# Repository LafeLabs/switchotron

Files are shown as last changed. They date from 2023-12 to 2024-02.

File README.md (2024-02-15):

# [SWITCHOTRON](https://github.com/lafelabs/switchotron/)

### [localhost](http://localhost/)

## 6 channel switch control code:

```

#include <Adafruit_NeoPixel.h>
#ifdef __AVR__
#endif

// Which pin on the Arduino is connected to the NeoPixels?
#define PIN        12 // On Trinket or Gemma, suggest changing this to 1

// How many NeoPixels are attached to the Arduino?
#define NUMPIXELS 6 // Popular NeoPixel ring size
//there are 8 neopixels but this code is for 6 used along with 6 buttons

// When setting up the NeoPixel library, we tell it how many pixels,  
// and which pin to use to send signals. Note that for older NeoPixel
// strips you might need to change the third parameter -- see the
// strandtest example for more information on possible values.
Adafruit_NeoPixel pixels(NUMPIXELS, PIN, NEO_GRB + NEO_KHZ800);

int analog = 0;
int delta = 100;
int mode = 1;//modes are 1,2,3,4,5, and 6 which are pixel 5,4,3,2,1, and 0 respectively

void setup() {
   Serial.begin(115200);

  // These lines are specifically to support the Adafruit Trinket 5V 16 MHz.
  // Any other board, you can remove this part (but no harm leaving it):
#if defined(__AVR_ATtiny85__) && (F_CPU == 16000000)
  clock_prescale_set(clock_div_1);
#endif
  // END of Trinket-specific code.

    pinMode(3,OUTPUT);
    pinMode(4,OUTPUT);
    pinMode(5,OUTPUT);
    pinMode(6,OUTPUT);
    pinMode(7,OUTPUT);
    pinMode(8,OUTPUT);

    digitalWrite(3,LOW);
    digitalWrite(4,LOW);
    digitalWrite(5,LOW);
    digitalWrite(6,LOW);
    digitalWrite(7,LOW);
    digitalWrite(8,LOW);

  pixels.begin(); // INITIALIZE NeoPixel strip object (REQUIRED)

}

void loop() {
  pixels.clear(); // Set all pixel colors to 'off'
  analog = analogRead(A0);
  // The first NeoPixel in a strand is #0, second is 1, all the way up
  // to the count of pixels minus one.
  
  if(analog > 1024 - delta){
    delay(1);
    analog = analogRead(A0);
    if(analog > 1023 - delta){
       mode = 1;      
    }
  }
  if(analog > 781 - delta && analog < 781 + delta){
    delay(5);
    analog = analogRead(A0);
    if(analog > 781 - delta && analog < 781 + delta){
         mode = 2; 
    }
  }
  if(analog > 593 - delta && analog < 593 + delta){
     delay(5);
     analog = analogRead(A0);

    if(analog > 593 - delta && analog < 593 + delta){
      mode = 3;    
    }
  }

  if(analog > 436 - delta && analog < 436 + delta){
     delay(1);
     analog = analogRead(A0);

    if(analog > 436 - delta && analog < 436 + delta){
      mode = 4;    
    }
  }

  if(analog > 296 - delta && analog < 296 + delta){
     delay(1);
     analog = analogRead(A0);

    if(analog > 296 - delta && analog < 296 + delta){
      mode = 5;    
    }
  }

  if(analog > 154 - delta && analog < 154 + delta){
     delay(1);
     analog = analogRead(A0);

    if(analog > 154 - delta && analog < 154 + delta){
      mode = 6;    
    }
  }

  if (Serial.available()) {

    //for more info on this code see http://adam-meyer.com/arduino/arduino-serial
    //read serial as ascii integer
        int ser = Serial.read();
    //    Serial.println(ser);
     if(ser == 49){    //ASCII for 1
      mode = 1;
     }
     if(ser == 50){    //ASCII for 2
      mode = 2;
     }
     if(ser == 51){    //ASCII for 3
      mode = 3;
     }
     if(ser == 52){    //ASCII for 4
      mode = 4;
     }
     if(ser == 53){    //ASCII for 5
      mode = 5;
     }
     if(ser == 54){    //ASCII for 6
      mode = 6;
     }

  }

  if(mode == 1){
    pixels.setPixelColor(0, pixels.Color(0, 0, 0));    
    pixels.setPixelColor(1, pixels.Color(0, 0, 0));    
    pixels.setPixelColor(2, pixels.Color(0, 0, 0));    
    pixels.setPixelColor(3, pixels.Color(0, 0, 0));    
    pixels.setPixelColor(4, pixels.Color(0, 0, 0));    
    pixels.setPixelColor(5, pixels.Color(255, 0, 0));    

    digitalWrite(3,HIGH);
    digitalWrite(4,LOW);
    digitalWrite(5,LOW);
    digitalWrite(6,LOW);
    digitalWrite(7,LOW);
    digitalWrite(8,LOW);
    
  }
  if(mode == 2){
    pixels.setPixelColor(0, pixels.Color(0, 0, 0));    
    pixels.setPixelColor(1, pixels.Color(0, 0, 0));    
    pixels.setPixelColor(2, pixels.Color(0, 0, 0));    
    pixels.setPixelColor(3, pixels.Color(0, 0, 0));    
    pixels.setPixelColor(4, pixels.Color(255, 165, 0));    
    pixels.setPixelColor(5, pixels.Color(0, 0, 0));    
    digitalWrite(3,LOW);
    digitalWrite(4,HIGH);
    digitalWrite(5,LOW);
    digitalWrite(6,LOW);
    digitalWrite(7,LOW);
    digitalWrite(8,LOW);
 
  }
  if(mode == 3){
    pixels.setPixelColor(0, pixels.Color(0, 0, 0));    
    pixels.setPixelColor(1, pixels.Color(0, 0, 0));    
    pixels.setPixelColor(2, pixels.Color(0, 0, 0));    
    pixels.setPixelColor(3, pixels.Color(255, 215, 0));    
    pixels.setPixelColor(4, pixels.Color(0, 0, 0));    
    pixels.setPixelColor(5, pixels.Color(0, 0, 0));    
    digitalWrite(3,LOW);
    digitalWrite(4,LOW);
    digitalWrite(5,HIGH);
    digitalWrite(6,LOW);
    digitalWrite(7,LOW);
    digitalWrite(8,LOW);
  }
  if(mode == 4){
    pixels.setPixelColor(0, pixels.Color(0, 0, 0));    
    pixels.setPixelColor(1, pixels.Color(0, 0, 0));    
    pixels.setPixelColor(2, pixels.Color(0, 255, 0));    
    pixels.setPixelColor(3, pixels.Color(0, 0, 0));    
    pixels.setPixelColor(4, pixels.Color(0, 0, 0));    
    pixels.setPixelColor(5, pixels.Color(0, 0, 0));    
    digitalWrite(3,LOW);
    digitalWrite(4,LOW);
    digitalWrite(5,LOW);
    digitalWrite(6,HIGH);
    digitalWrite(7,LOW);
    digitalWrite(8,LOW);
  }
  if(mode == 5){
    pixels.setPixelColor(0, pixels.Color(0, 0, 0));    
    pixels.setPixelColor(1, pixels.Color(0, 0, 255));    
    pixels.setPixelColor(2, pixels.Color(0, 0, 0));    
    pixels.setPixelColor(3, pixels.Color(0, 0, 0));    
    pixels.setPixelColor(4, pixels.Color(0, 0, 0));    
    pixels.setPixelColor(5, pixels.Color(0, 0, 0));    
    digitalWrite(3,LOW);
    digitalWrite(4,LOW);
    digitalWrite(5,LOW);
    digitalWrite(6,LOW);
    digitalWrite(7,HIGH);
    digitalWrite(8,LOW);
  }
  if(mode == 6){
    pixels.setPixelColor(0, pixels.Color(200, 0, 200));    
    pixels.setPixelColor(1, pixels.Color(0, 0, 0));    
    pixels.setPixelColor(2, pixels.Color(0, 0, 0));    
    pixels.setPixelColor(3, pixels.Color(0, 0, 0));    
    pixels.setPixelColor(4, pixels.Color(0, 0, 0));    
    pixels.setPixelColor(5, pixels.Color(0, 0, 0));    
    digitalWrite(3,LOW);
    digitalWrite(4,LOW);
    digitalWrite(5,LOW);
    digitalWrite(6,LOW);
    digitalWrite(7,LOW);
    digitalWrite(8,HIGH);
  }
  
  pixels.show();   // Send the updated pixel colors to the hardware.
  delay(1); // Pause before next pass through loop

    Serial.println(analog);

}
```
## 9 Channel Control Code:

```

#include <Adafruit_NeoPixel.h>
#ifdef __AVR__
#endif

// Which pin on the Arduino is connected to the NeoPixels?
#define PIN        12 // On Trinket or Gemma, suggest changing this to 1

// How many NeoPixels are attached to the Arduino?
#define NUMPIXELS 9 // 
//there are 9

// When setting up the NeoPixel library, we tell it how many pixels,  
// and which pin to use to send signals. Note that for older NeoPixel
// strips you might need to change the third parameter -- see the
// strandtest example for more information on possible values.
Adafruit_NeoPixel pixels(NUMPIXELS, PIN, NEO_GRB + NEO_KHZ800);

int analog = 0;
int delta = 20;
int mode = 1;//modes are 1,2,3,4,5,6,7,8,9 which are pixel 8,7,6,5,4,3,2,1, and 0 respectively

void setup() {
    Serial.begin(115200);

  // These lines are specifically to support the Adafruit Trinket 5V 16 MHz.
  // Any other board, you can remove this part (but no harm leaving it):
#if defined(__AVR_ATtiny85__) && (F_CPU == 16000000)
  clock_prescale_set(clock_div_1);
#endif
  // END of Trinket-specific code.

    pinMode(3,OUTPUT);
    pinMode(4,OUTPUT);
    pinMode(5,OUTPUT);
    pinMode(6,OUTPUT);
    pinMode(7,OUTPUT);
    pinMode(8,OUTPUT);

    digitalWrite(3,LOW);
    digitalWrite(4,LOW);
    digitalWrite(5,LOW);
    digitalWrite(6,LOW);
    digitalWrite(7,LOW);
    digitalWrite(8,LOW);

  pixels.begin(); // INITIALIZE NeoPixel strip object (REQUIRED)

}

void loop() {

  pixels.clear(); // Set all pixel colors to 'off'
  analog = analogRead(A0);
  // The first NeoPixel in a strand is #0, second is 1, all the way up
  // to the count of pixels minus one.
  
  if(analog > 1024 - delta){
    delay(1);
    analog = analogRead(A0);
    if(analog > 1023 - delta){
       mode = 1;      
    }
  }
  if(analog > 836 - delta && analog < 836 + delta){
    delay(5);
    analog = analogRead(A0);
    if(analog > 836 - delta && analog < 836 + delta){
         mode = 2; 
    }
  }
  if(analog > 690 - delta && analog < 690 + delta){
     delay(5);
     analog = analogRead(A0);

    if(analog > 690 - delta && analog < 690 + delta){
      mode = 3;    
    }
  }

  if(analog > 569 - delta && analog < 569 + delta){
     delay(1);
     analog = analogRead(A0);

    if(analog > 569 - delta && analog < 569 + delta){
      mode = 4;    
    }
  }

  if(analog > 464 - delta && analog < 464 + delta){
     delay(1);
     analog = analogRead(A0);

    if(analog > 464 - delta && analog < 464 + delta){
      mode = 5;    
    }
  }

  if(analog > 372 - delta && analog < 372 + delta){
     delay(1);
     analog = analogRead(A0);

    if(analog > 372 - delta && analog < 372 + delta){
      mode = 6;    
    }
  }

  if(analog > 283 - delta && analog < 283 + delta){
     delay(1);
     analog = analogRead(A0);

    if(analog > 283 - delta && analog < 283 + delta){
      mode = 7;    
    }
  }

  if(analog > 195 - delta && analog < 195 + delta){
     delay(1);
     analog = analogRead(A0);

    if(analog > 195 - delta && analog < 195 + delta){
      mode = 8;    
    }
  }

  if(analog > 103 - delta && analog < 103 + delta){
     delay(1);
     analog = analogRead(A0);

    if(analog > 103 - delta && analog < 103 + delta){
      mode = 9;    
    }
  }

  if (Serial.available()) {

    //for more info on this code see http://adam-meyer.com/arduino/arduino-serial
    //read serial as ascii integer
     int ser = Serial.read();
    //    Serial.println(ser);
     if(ser == 49){    //ASCII for 1
      mode = 1;
     }
     if(ser == 50){    //ASCII for 2
      mode = 2;
     }
     if(ser == 51){    //ASCII for 3
      mode = 3;
     }
     if(ser == 52){    //ASCII for 4
      mode = 4;
     }
     if(ser == 53){    //ASCII for 5
      mode = 5;
     }
     if(ser == 54){    //ASCII for 6
      mode = 6;
     }
     if(ser == 55){    //ASCII for 4
      mode = 7;
     }
     if(ser == 56){    //ASCII for 5
      mode = 8;
     }
     if(ser == 57){    //ASCII for 6
      mode = 9;
     }

  }

  if(mode == 1){
    pixels.setPixelColor(0, pixels.Color(0, 0, 0));    
    pixels.setPixelColor(1, pixels.Color(0, 0, 0));    
    pixels.setPixelColor(2, pixels.Color(0, 0, 0));    
    pixels.setPixelColor(3, pixels.Color(0, 0, 0));    
    pixels.setPixelColor(4, pixels.Color(0, 0, 0));    
    pixels.setPixelColor(5, pixels.Color(0, 0, 0));    
    pixels.setPixelColor(6, pixels.Color(0, 0, 0));    
    pixels.setPixelColor(7, pixels.Color(0, 0, 0));    
    pixels.setPixelColor(8, pixels.Color(255, 0, 0));    
    digitalWrite(3,HIGH);
    digitalWrite(4,LOW);
    digitalWrite(5,LOW);
    digitalWrite(6,HIGH);
    digitalWrite(7,LOW);
    digitalWrite(8,LOW);

  }
  if(mode == 2){
    pixels.setPixelColor(0, pixels.Color(0, 0, 0));    
    pixels.setPixelColor(1, pixels.Color(0, 0, 0));    
    pixels.setPixelColor(2, pixels.Color(0, 0, 0));    
    pixels.setPixelColor(3, pixels.Color(0, 0, 0));    
    pixels.setPixelColor(4, pixels.Color(0, 0, 0));    
    pixels.setPixelColor(5, pixels.Color(0, 0, 0));    
    pixels.setPixelColor(6, pixels.Color(0, 0, 0));    
    pixels.setPixelColor(7, pixels.Color(255, 0, 0));    
    pixels.setPixelColor(8, pixels.Color(0, 0, 0));    
    digitalWrite(3,HIGH);
    digitalWrite(4,LOW);
    digitalWrite(5,LOW);
    digitalWrite(6,LOW);
    digitalWrite(7,HIGH);
    digitalWrite(8,LOW);

  }
  if(mode == 3){
    pixels.setPixelColor(0, pixels.Color(0, 0, 0));    
    pixels.setPixelColor(1, pixels.Color(0, 0, 0));    
    pixels.setPixelColor(2, pixels.Color(0, 0, 0));    
    pixels.setPixelColor(3, pixels.Color(0, 0, 0));    
    pixels.setPixelColor(4, pixels.Color(0, 0, 0));    
    pixels.setPixelColor(5, pixels.Color(0, 0, 0));    
    pixels.setPixelColor(6, pixels.Color(255, 0, 0));    
    pixels.setPixelColor(7, pixels.Color(0, 0, 0));    
    pixels.setPixelColor(8, pixels.Color(0, 0, 0));    
    digitalWrite(3,HIGH);
    digitalWrite(4,LOW);
    digitalWrite(5,LOW);
    digitalWrite(6,LOW);
    digitalWrite(7,LOW);
    digitalWrite(8,HIGH);

  }
  if(mode == 4){
    pixels.setPixelColor(0, pixels.Color(0, 0, 0));    
    pixels.setPixelColor(1, pixels.Color(0, 0, 0));    
    pixels.setPixelColor(2, pixels.Color(0, 0, 0));    
    pixels.setPixelColor(3, pixels.Color(0, 0, 0));    
    pixels.setPixelColor(4, pixels.Color(0, 0, 0));    
    pixels.setPixelColor(5, pixels.Color(255, 0, 0));    
    pixels.setPixelColor(6, pixels.Color(0, 0, 0));    
    pixels.setPixelColor(7, pixels.Color(0, 0, 0));    
    pixels.setPixelColor(8, pixels.Color(0, 0, 0));    
    digitalWrite(3,LOW);
    digitalWrite(4,HIGH);
    digitalWrite(5,LOW);
    digitalWrite(6,HIGH);
    digitalWrite(7,LOW);
    digitalWrite(8,LOW);

  }
  if(mode == 5){
    pixels.setPixelColor(0, pixels.Color(0, 0, 0));    
    pixels.setPixelColor(1, pixels.Color(0, 0, 0));    
    pixels.setPixelColor(2, pixels.Color(0, 0, 0));    
    pixels.setPixelColor(3, pixels.Color(0, 0, 0));    
    pixels.setPixelColor(4, pixels.Color(255, 0, 0));    
    pixels.setPixelColor(5, pixels.Color(0, 0, 0));    
    pixels.setPixelColor(6, pixels.Color(0, 0, 0));    
    pixels.setPixelColor(7, pixels.Color(0, 0, 0));    
    pixels.setPixelColor(8, pixels.Color(0, 0, 0));    
    digitalWrite(3,LOW);
    digitalWrite(4,HIGH);
    digitalWrite(5,LOW);
    digitalWrite(6,LOW);
    digitalWrite(7,HIGH);
    digitalWrite(8,LOW);

  }
  if(mode == 6){
    pixels.setPixelColor(0, pixels.Color(0, 0, 0));    
    pixels.setPixelColor(1, pixels.Color(0, 0, 0));    
    pixels.setPixelColor(2, pixels.Color(0, 0, 0));    
    pixels.setPixelColor(3, pixels.Color(255, 0, 0));    
    pixels.setPixelColor(4, pixels.Color(0, 0, 0));    
    pixels.setPixelColor(5, pixels.Color(0, 0, 0));    
    pixels.setPixelColor(6, pixels.Color(0, 0, 0));    
    pixels.setPixelColor(7, pixels.Color(0, 0, 0));    
    pixels.setPixelColor(8, pixels.Color(0, 0, 0));    
    digitalWrite(3,LOW);
    digitalWrite(4,HIGH);
    digitalWrite(5,LOW);
    digitalWrite(6,LOW);
    digitalWrite(7,LOW);
    digitalWrite(8,HIGH);

  }

  if(mode == 7){
    pixels.setPixelColor(0, pixels.Color(0, 0, 0));    
    pixels.setPixelColor(1, pixels.Color(0, 0, 0));    
    pixels.setPixelColor(2, pixels.Color(255, 0, 0));    
    pixels.setPixelColor(3, pixels.Color(0, 0, 0));    
    pixels.setPixelColor(4, pixels.Color(0, 0, 0));    
    pixels.setPixelColor(5, pixels.Color(0, 0, 0));    
    pixels.setPixelColor(6, pixels.Color(0, 0, 0));    
    pixels.setPixelColor(7, pixels.Color(0, 0, 0));    
    pixels.setPixelColor(8, pixels.Color(0, 0, 0));    
    digitalWrite(3,LOW);
    digitalWrite(4,LOW);
    digitalWrite(5,HIGH);
    digitalWrite(6,HIGH);
    digitalWrite(7,LOW);
    digitalWrite(8,LOW);

 }
  if(mode == 8){
    pixels.setPixelColor(0, pixels.Color(0, 0, 0));    
    pixels.setPixelColor(1, pixels.Color(255, 0, 0));    
    pixels.setPixelColor(2, pixels.Color(0, 0, 0));    
    pixels.setPixelColor(3, pixels.Color(0, 0, 0));    
    pixels.setPixelColor(4, pixels.Color(0, 0, 0));    
    pixels.setPixelColor(5, pixels.Color(0, 0, 0));    
    pixels.setPixelColor(6, pixels.Color(0, 0, 0));    
    pixels.setPixelColor(7, pixels.Color(0, 0, 0));    
    pixels.setPixelColor(8, pixels.Color(0, 0, 0));    
    digitalWrite(3,LOW);
    digitalWrite(4,LOW);
    digitalWrite(5,HIGH);
    digitalWrite(6,LOW);
    digitalWrite(7,HIGH);
    digitalWrite(8,LOW);

  }
  if(mode == 9){
    pixels.setPixelColor(0, pixels.Color(255, 0, 0));    
    pixels.setPixelColor(1, pixels.Color(0, 0, 0));    
    pixels.setPixelColor(2, pixels.Color(0, 0, 0));    
    pixels.setPixelColor(3, pixels.Color(0, 0, 0));    
    pixels.setPixelColor(4, pixels.Color(0, 0, 0));    
    pixels.setPixelColor(5, pixels.Color(0, 0, 0));    
    pixels.setPixelColor(6, pixels.Color(0, 0, 0));    
    pixels.setPixelColor(7, pixels.Color(0, 0, 0));    
    pixels.setPixelColor(8, pixels.Color(0, 0, 0));    
    digitalWrite(3,LOW);
    digitalWrite(4,LOW);
    digitalWrite(5,HIGH);
    digitalWrite(6,LOW);
    digitalWrite(7,LOW);
    digitalWrite(8,HIGH);

  }

  pixels.show();   // Send the updated pixel colors to the hardware.
  delay(1); // Pause before next pass through loop

//    Serial.println(analog);

}

```

The switch as sign, using GEOMETRON.

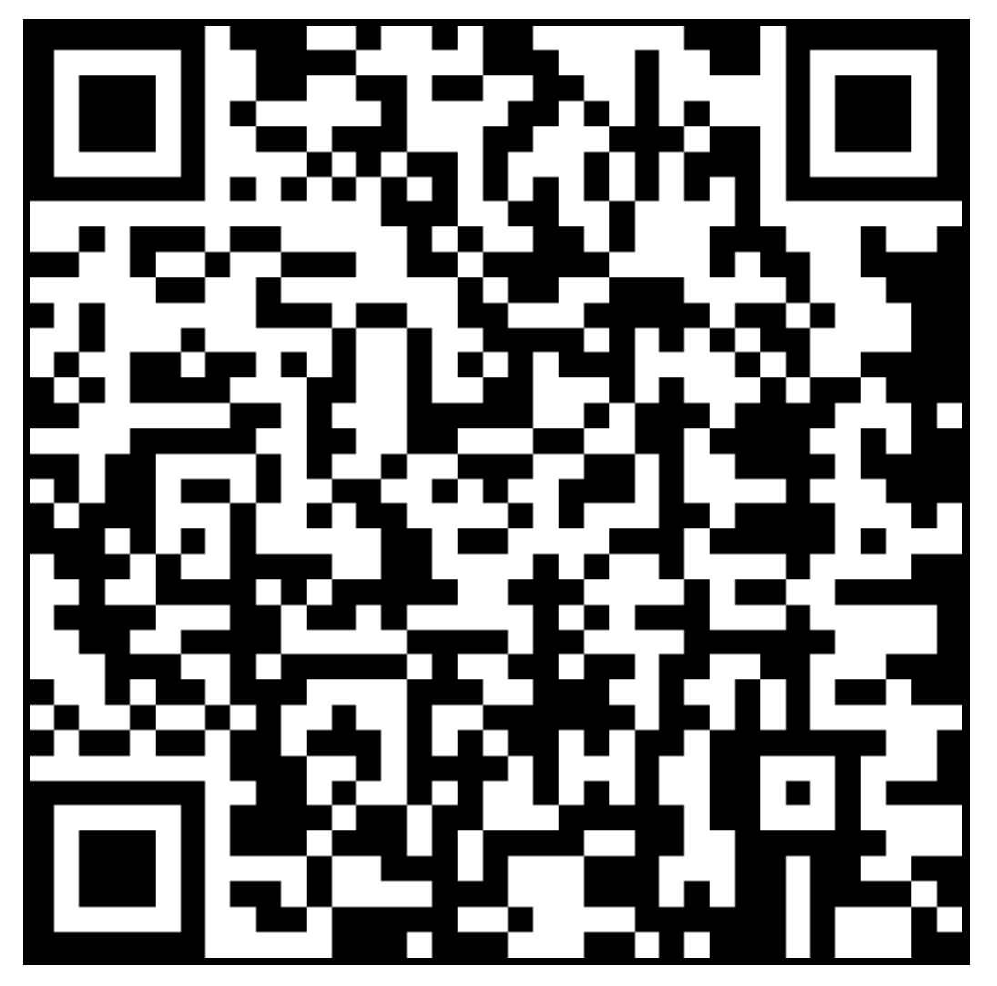
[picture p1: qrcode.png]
qr code pointing to github repository


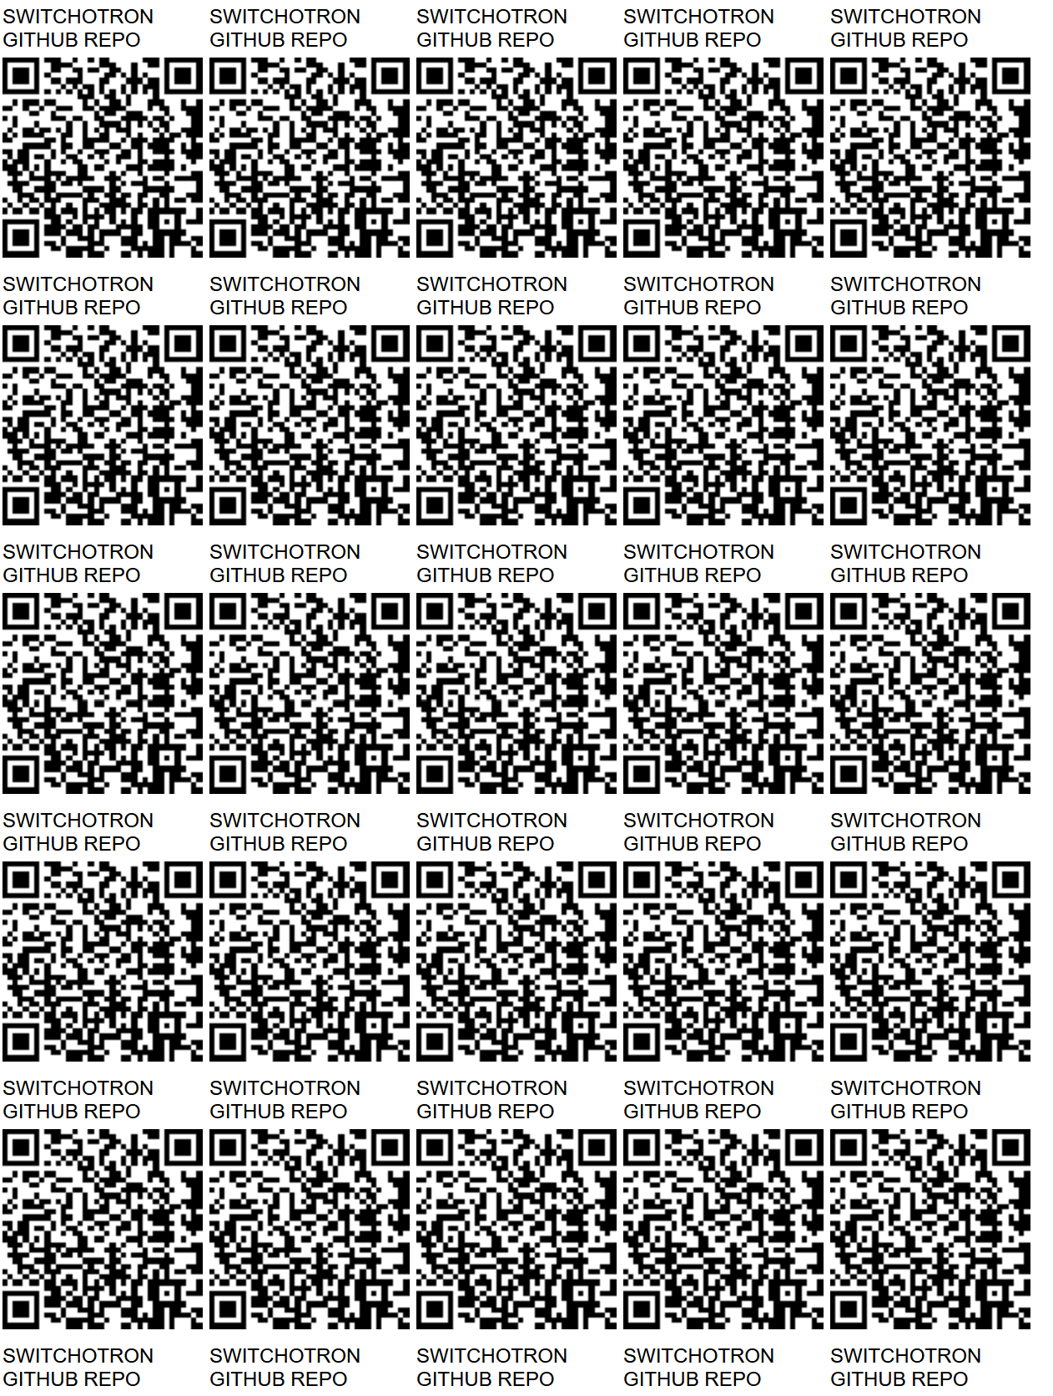
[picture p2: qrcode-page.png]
a whole page of qr codes to print out


This is a modular system of Arduino-based switch controllers for metrology.  The relay board is laid out on a 10 inch by 10 inch square, cut from acrylic or wood on a laser cutter or with a saw and drill.  

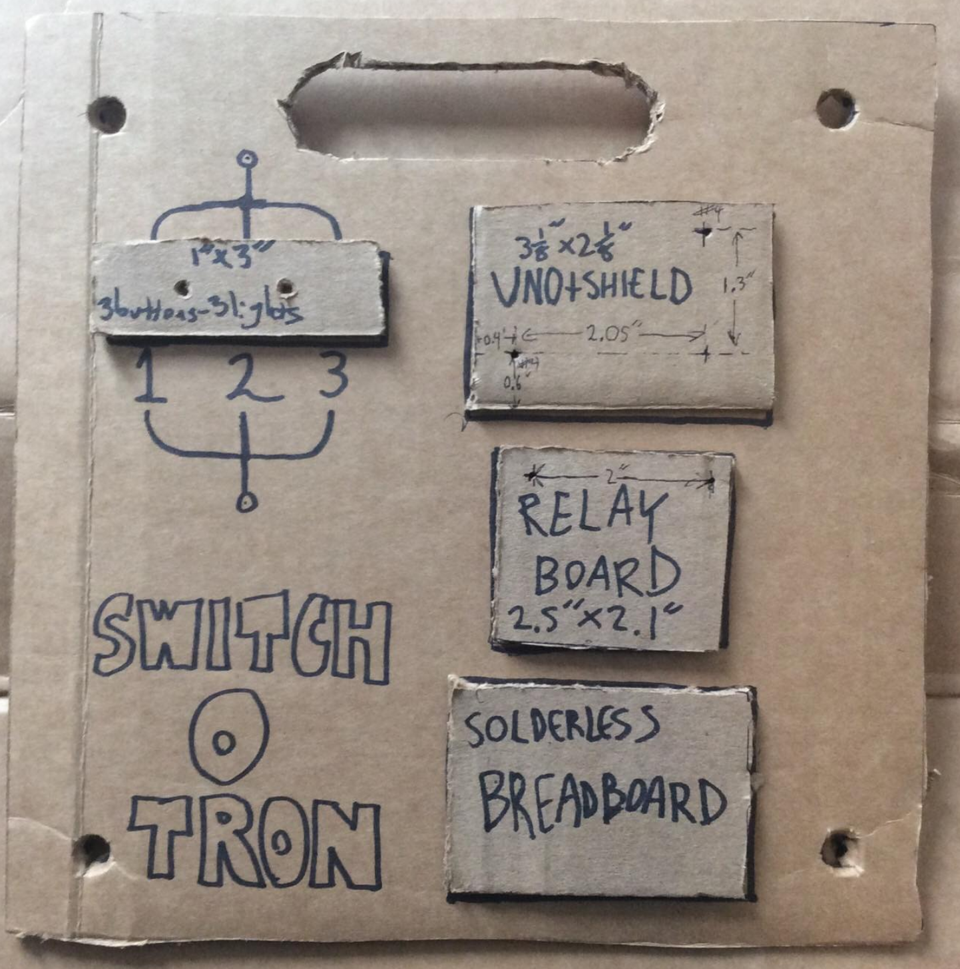
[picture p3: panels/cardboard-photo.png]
photo of cardboard model of system


pattern laid out in geometron of main square

# UNO SHIELD BOARD

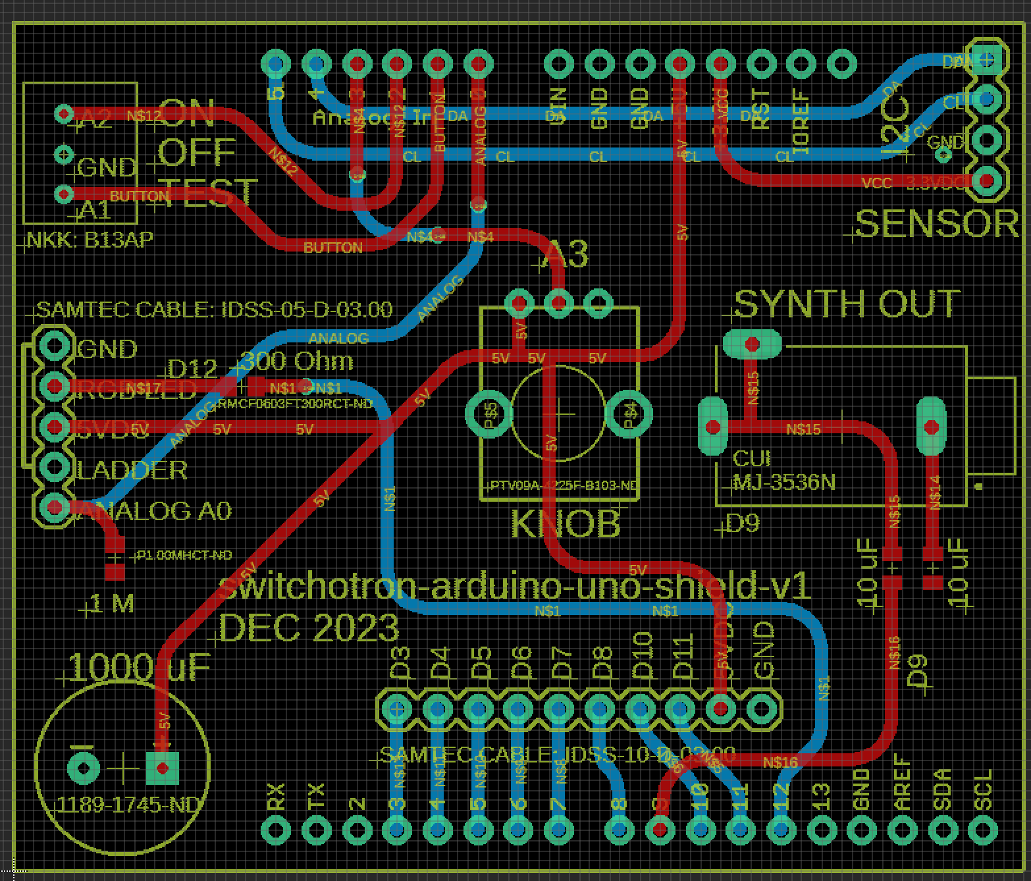
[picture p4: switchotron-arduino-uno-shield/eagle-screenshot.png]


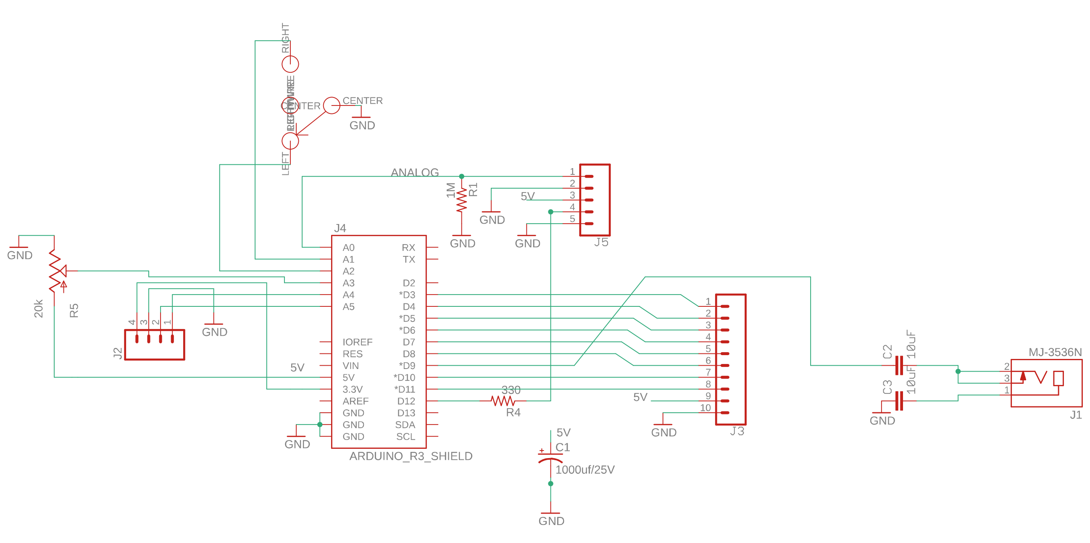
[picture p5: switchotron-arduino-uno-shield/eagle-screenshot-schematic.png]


### EAGLE FILES

 - [switchotron-arduino-uno-shield-v1.brd](https://raw.githubusercontent.com/LafeLabs/switchotron/main/switchotron-arduino-uno-shield/switchotron-arduino-uno-shield-v1.brd)
 - [switchotron-arduino-uno-shield-v1.sch](https://raw.githubusercontent.com/LafeLabs/switchotron/main/switchotron-arduino-uno-shield/switchotron-arduino-uno-shield-v1.sch)

### GERBER FILES

 - [switchotron-arduino-uno-shield-v1-gerbers.zip](https://github.com/LafeLabs/switchotron/raw/main/switchotron-arduino-uno-shield/switchotron-arduino-uno-shield-v1-gerbers.zip)

### PART LINKS

 - [Audio Jack part link on Digikey](https://www.digikey.com/en/products/detail/cui-devices/MJ-3536N/281264)
 - [10 uF SMT capacitor in 0603 package link on Digikey](https://www.digikey.com/en/products/detail/samsung-electro-mechanics/CL10A106MP8NNNC/3887529)
 - [1000 uF electrolytic capacitor link on Digikey](https://www.digikey.com/en/products/detail/rubycon/35PX1000MEFC10X20/3563769)
 - [300 Ohm SMT resistor in 0603 package link on Digikey](https://www.digikey.com/en/products/detail/stackpole-electronics-inc/RMCF0603FT300R/1760765)
 - [1 megaohm SMT resistor in 0603 package link on digikey](https://www.digikey.com/en/products/detail/panasonic-electronic-components/ERJ-3EKF1004V/196033)
 - [10 kiloohm potentiometer Digikey link](https://www.digikey.com/en/products/detail/bourns-inc/PTV09A-4225F-B103/3781155)
 - [Switch link on digikey](https://www.digikey.com/en/products/detail/nkk-switches/B13AP/379100)
 - [rainbow colored Male 0.1" header pin kit from Digikey/Adafruit](https://www.digikey.com/en/products/detail/adafruit-industries-llc/4154/10123805)
 - [SAMTEC IDSS-05-D-03.00 5 pin cable](https://www.samtec.com/products/idss-05-d-03.00)
 - [SAMTEC IDSS-10-D-03.00 10 pin cable](https://www.samtec.com/products/idss-10-d-03.00)
 - [SAMTEC datasheet](https://www.mouser.com/datasheet/2/527/idmd-2508302.pdf)

# 3 BUTTONS 3 LIGHTS BOARD

This board turned out to have the WS2811 pad on the first version, which is wrong!  The neopixel boards are all now the WS2812B.  

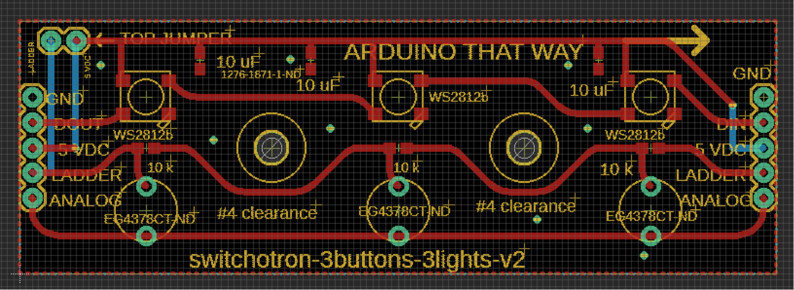
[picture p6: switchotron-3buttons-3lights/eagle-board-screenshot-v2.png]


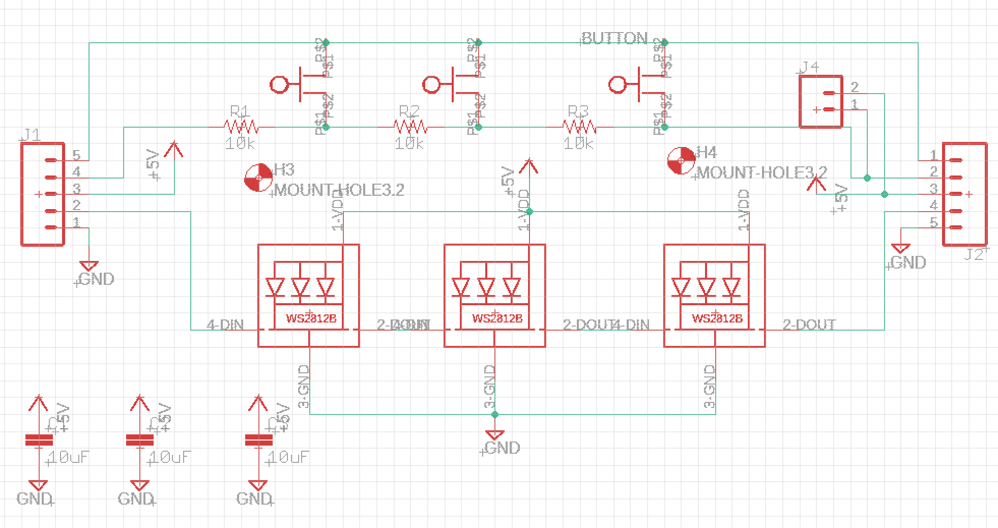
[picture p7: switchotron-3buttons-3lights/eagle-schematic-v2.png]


here is the version 1 board showing how the neopixel doesn't fit:

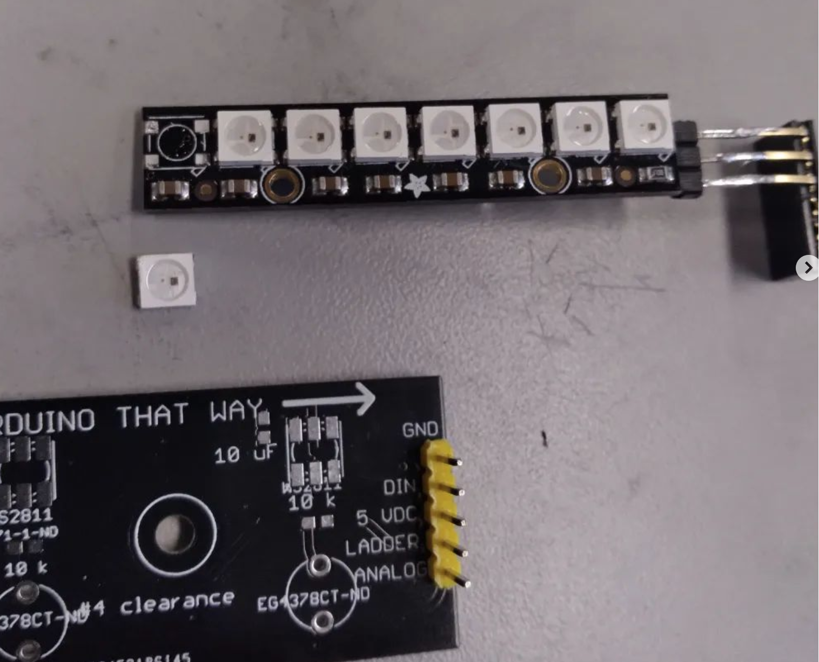
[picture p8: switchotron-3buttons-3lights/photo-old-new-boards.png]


WS2812 layout and pins:

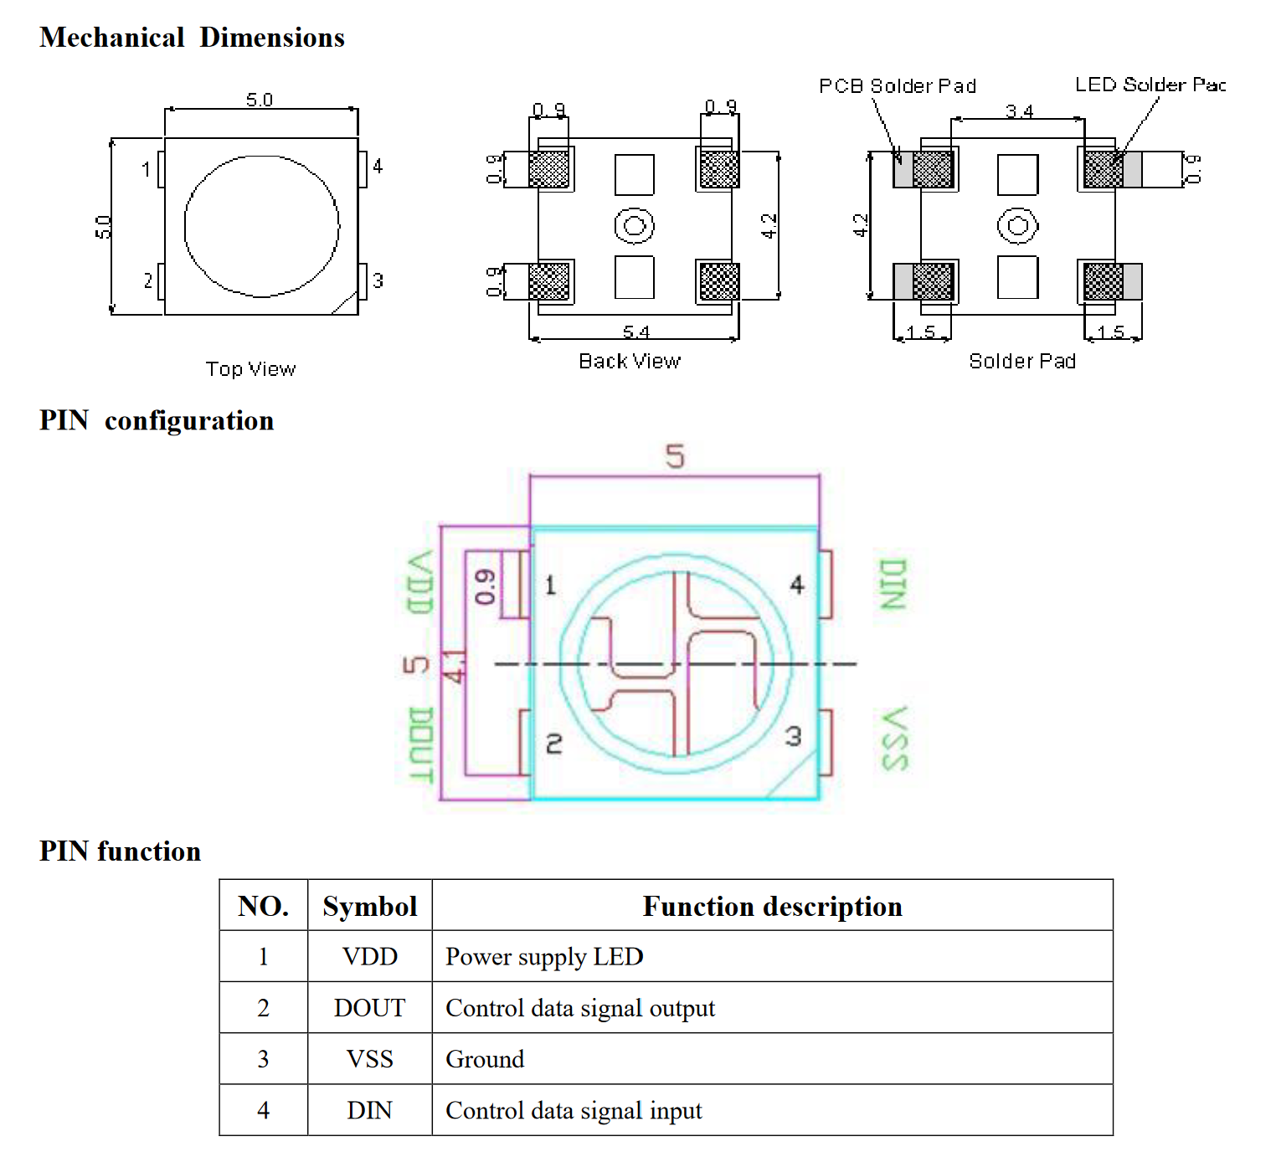
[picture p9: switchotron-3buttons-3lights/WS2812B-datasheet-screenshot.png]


#### EAGLE FILES

 - [switchotron-3buttons-3lights-v2.brd](https://raw.githubusercontent.com/LafeLabs/switchotron/main/switchotron-3buttons-3lights/switchotron-3buttons-3lights-v2.brd)
 - [switchotron-3buttons-3lights-v2.sch](https://raw.githubusercontent.com/LafeLabs/switchotron/main/switchotron-3buttons-3lights/switchotron-3buttons-3lights-v2.sch)

### GERBER FILES

 - [switchotron-3buttons-3lights-v2-gerbers.zip](https://github.com/LafeLabs/switchotron/raw/main/switchotron-3buttons-3lights/switchotron-3buttons-3lights-v2-gerbers.zip)

###  PARTS LINKS

 - [WS2812B LED NEOPIXELS](https://www.digikey.com/en/products/detail/sparkfun-electronics/COM-16347/11630204)
 - [10 uF Capacitors](https://www.digikey.com/en/products/detail/samsung-electro-mechanics/CL10A106MP8NNNC/3887529)
 - [10 k resistors](https://www.digikey.com/en/products/detail/stackpole-electronics-inc/RMCF0603FT10K0/1761235)
 - [buttons](https://www.digikey.com/en/products/detail/e-switch/TL59AF100Q/1144803)
 - [headers](https://www.digikey.com/en/products/detail/adafruit-industries-llc/4154/10123805)

# RELAY BOARD

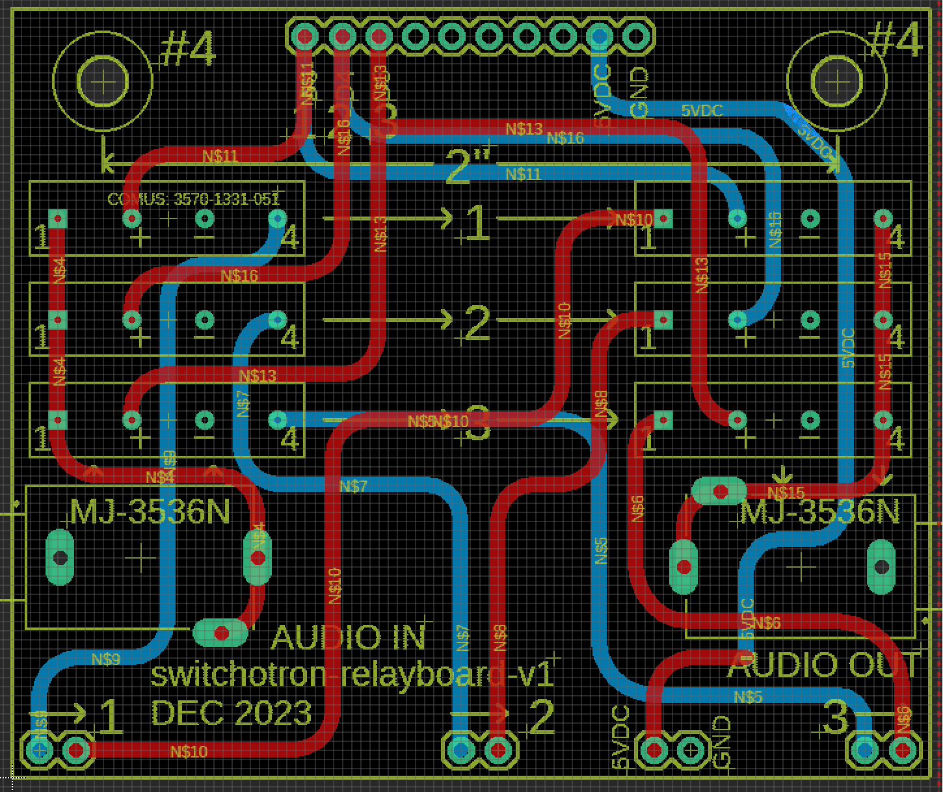
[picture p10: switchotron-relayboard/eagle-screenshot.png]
 

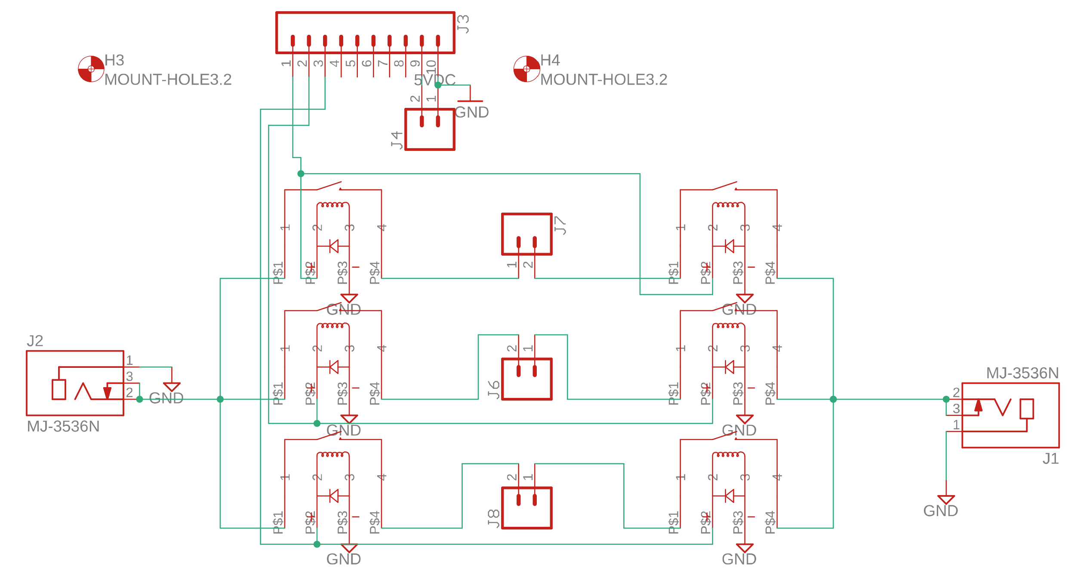
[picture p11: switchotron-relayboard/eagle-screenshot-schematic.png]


### EAGLE FILES

 - [switchotron-relayboard-v1.brd](https://raw.githubusercontent.com/LafeLabs/switchotron/main/switchotron-relayboard/switchotron-relayboard-v1.brd)
 - [switchotron-relayboard-v1.sch](https://raw.githubusercontent.com/LafeLabs/switchotron/main/switchotron-relayboard/switchotron-relayboard-v1.sch)

### GERBER FILES

 - [switchotron-relayboard-v1-gerbers.zip](https://github.com/LafeLabs/switchotron/raw/main/switchotron-3buttons-3lights/switchotron-relayboard-v1-gerbers.zip)

### PARTS LINKS

 - [Audio Jack part link on Digikey](https://www.digikey.com/en/products/detail/cui-devices/MJ-3536N/281264)
 - [headers](https://www.digikey.com/en/products/detail/adafruit-industries-llc/4154/10123805)
 - [relays](https://www.digikey.com/en/products/detail/comus-international/3570-1331-051/7497098)

#### LASER CUTOUTS AND DIMENSIONS

CUT ALL SQUARES OUT 10 INCHES ON A SIDE:









CUT THIS OUT 19X7 INCHES:



ADD OR MODIFY HOLE POSITIONS AS NEEDED FOR BOARD WHICH ADAPTS TO FRIDGE CABLE.  

### ARDUINO BOARD DIMENSIONS AND HOLE LAYOUTS

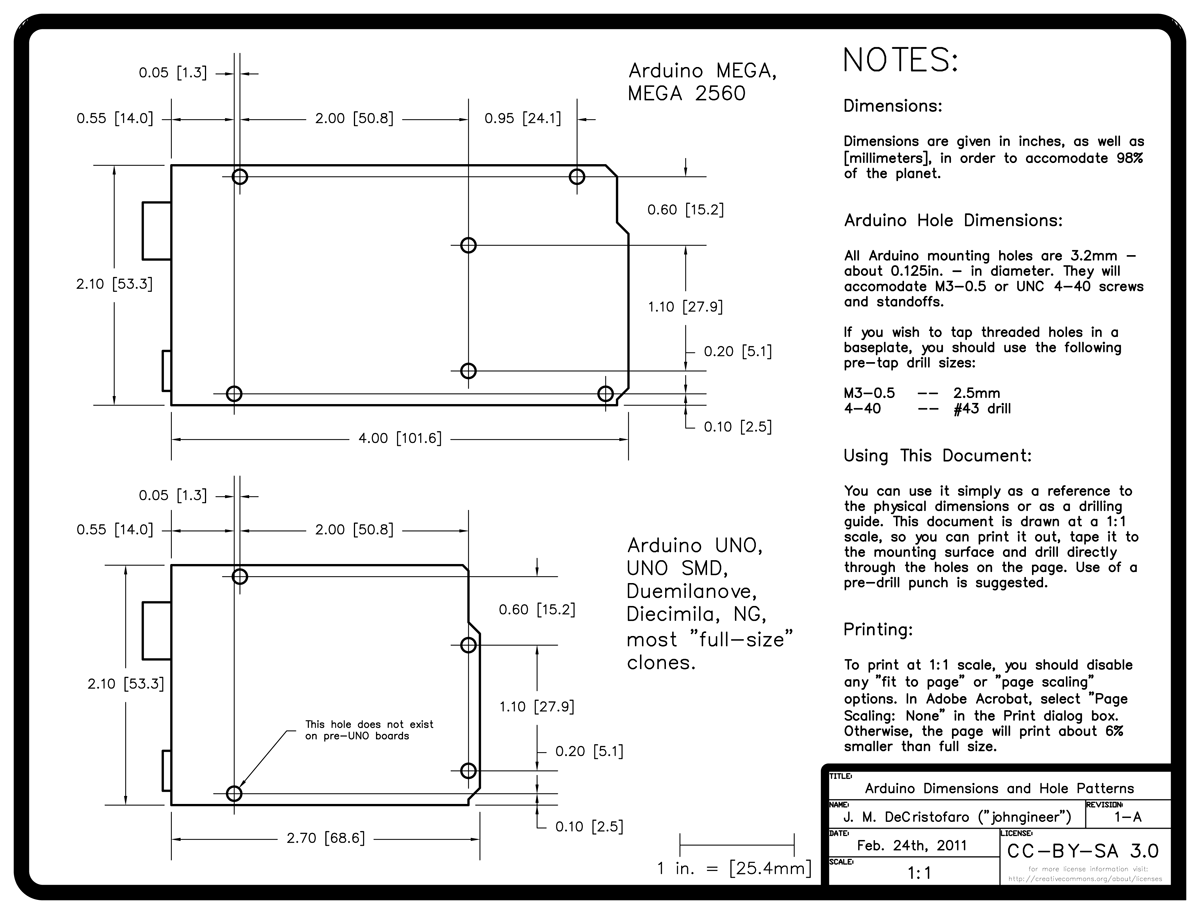
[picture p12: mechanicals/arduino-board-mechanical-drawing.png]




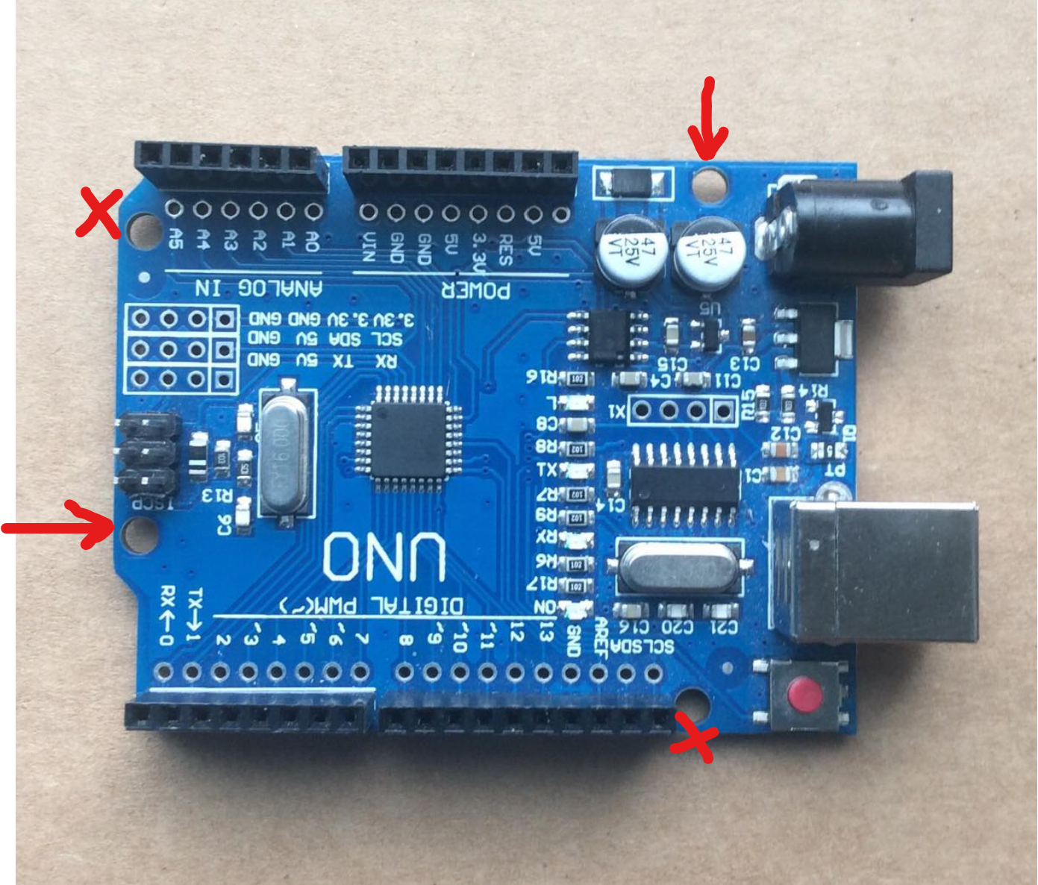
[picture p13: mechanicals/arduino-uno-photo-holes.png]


### FASTENERS FROM MCMASTER CARR

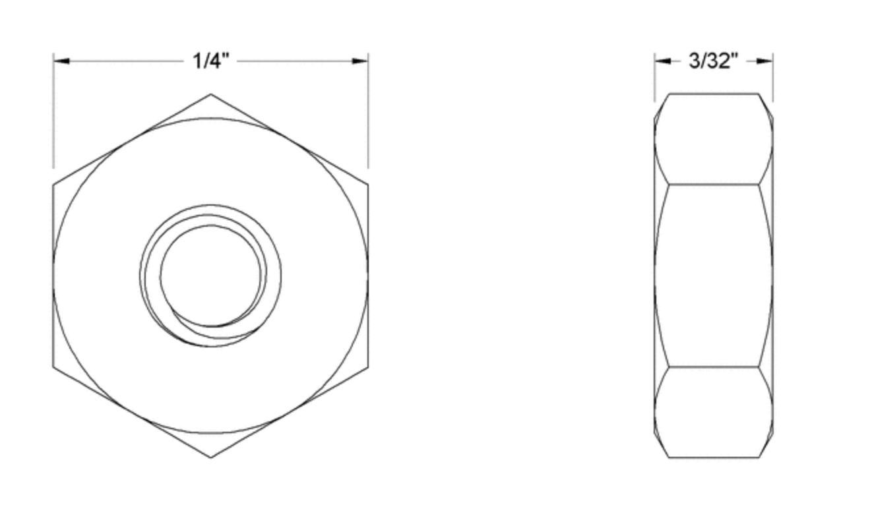
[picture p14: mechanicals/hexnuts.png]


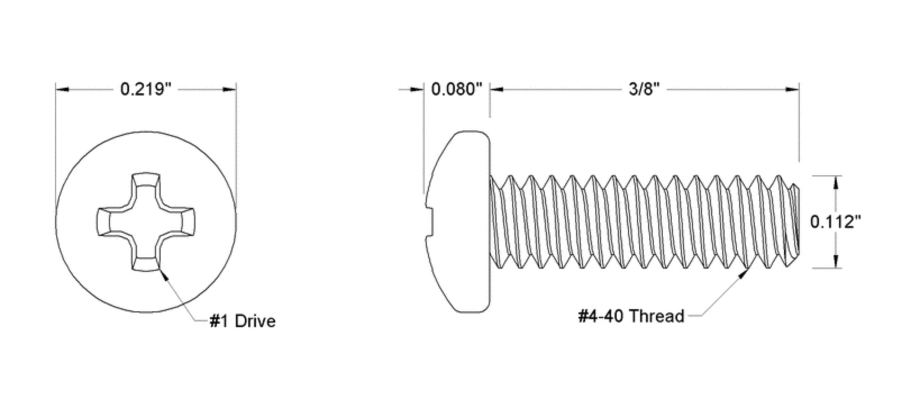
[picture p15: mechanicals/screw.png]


 - [4-40 brass hex nuts](https://www.mcmaster.com/92671A005/)
 - [4-40 3/8" long brass pan head Phillips screws](https://www.mcmaster.com/94070A108/)

# ARDUINO CODE TO SWITCH BETWEEN THREE RELAY STATES

BUTTONS ARE 1,2,3 FROM LEFT TO RIGHT, AND ARE RED, GREEN, THEN BLUE LIGHTS.  

```

#include <Adafruit_NeoPixel.h>
#ifdef __AVR__
#endif

// Which pin on the Arduino is connected to the NeoPixels?
#define PIN        12 // On Trinket or Gemma, suggest changing this to 1

// How many NeoPixels are attached to the Arduino?
#define NUMPIXELS 3 // Popular NeoPixel ring size

// When setting up the NeoPixel library, we tell it how many pixels,
// and which pin to use to send signals. Note that for older NeoPixel
// strips you might need to change the third parameter -- see the
// strandtest example for more information on possible values.
Adafruit_NeoPixel pixels(NUMPIXELS, PIN, NEO_GRB + NEO_KHZ800);

int analog = 0;
int delta = 100;
int mode = 1;//modes are 1,2, and 3, which are pixel 2,1, and 0 respectively

void setup() {
      Serial.begin(115200);

  // These lines are specifically to support the Adafruit Trinket 5V 16 MHz.
  // Any other board, you can remove this part (but no harm leaving it):
#if defined(__AVR_ATtiny85__) && (F_CPU == 16000000)
  clock_prescale_set(clock_div_1);
#endif
  // END of Trinket-specific code.

    pinMode(3,OUTPUT);
    pinMode(4,OUTPUT);
    pinMode(5,OUTPUT);
    digitalWrite(3,HIGH);
    digitalWrite(4,LOW);
    digitalWrite(5,LOW);

  pixels.begin(); // INITIALIZE NeoPixel strip object (REQUIRED)

}

void loop() {
  pixels.clear(); // Set all pixel colors to 'off'
  analog = analogRead(A0);
  // The first NeoPixel in a strand is #0, second is 1, all the way up
  // to the count of pixels minus one.
  
  if(analog > 1024 - delta){
    delay(1);
    analog = analogRead(A0);
    if(analog > 1024 - delta){
       mode = 1;      
    }
  }
  if(analog > (2*1024/3) - delta && analog < (2*1024/3) + delta){
    delay(1);
    analog = analogRead(A0);
    if(analog > (2*1024/3) - delta && analog < (2*1024/3) + delta){
         mode = 2; 
    }
  }
  if(analog > (1*1024/3) - delta && analog < (1*1024/3) + delta){
     delay(1);
     analog = analogRead(A0);

    if(analog > (1*1024/3) - delta && analog < (1*1024/3) + delta){
      mode = 3;
    
  }

  }
  if(mode == 1){
    pixels.setPixelColor(0, pixels.Color(0, 0, 0));    
    pixels.setPixelColor(1, pixels.Color(0, 0, 0));    
    pixels.setPixelColor(2, pixels.Color(200, 0, 0));    
    digitalWrite(4,LOW);
    digitalWrite(5,LOW);
    digitalWrite(3,HIGH);

  }
  if(mode == 2){
    pixels.setPixelColor(0, pixels.Color(0, 0, 0));    
    pixels.setPixelColor(1, pixels.Color(0, 200, 0));    
    pixels.setPixelColor(2, pixels.Color(0, 0, 0));    
    digitalWrite(3,LOW);
    digitalWrite(5,LOW);
    digitalWrite(4,HIGH);
 
  }
  if(mode == 3){
    pixels.setPixelColor(0, pixels.Color(0, 0, 200));    
     pixels.setPixelColor(1, pixels.Color(0, 0, 0));    
    pixels.setPixelColor(2, pixels.Color(0, 0, 0));    
    digitalWrite(4,LOW);
    digitalWrite(3,LOW);
    digitalWrite(5,HIGH);

  }
  pixels.show();   // Send the updated pixel colors to the hardware.
  delay(1); // Pause before next pass through loop

    Serial.println(analog);

}
```

## 8 LED array, using 6 pixels and 6 buttons code

```

#include <Adafruit_NeoPixel.h>
#ifdef __AVR__
#endif

// Which pin on the Arduino is connected to the NeoPixels?
#define PIN        12 // On Trinket or Gemma, suggest changing this to 1

// How many NeoPixels are attached to the Arduino?
#define NUMPIXELS 8 // Popular NeoPixel ring size
//there are 8 neopixels but this code is for 6 used along with 6 buttons

// When setting up the NeoPixel library, we tell it how many pixels,  
// and which pin to use to send signals. Note that for older NeoPixel
// strips you might need to change the third parameter -- see the
// strandtest example for more information on possible values.
Adafruit_NeoPixel pixels(NUMPIXELS, PIN, NEO_GRB + NEO_KHZ800);

int analog = 0;
int delta = 100;
int mode = 1;//modes are 1,2,3,4,5, and 6 which are pixel 5,4,3,2,1, and 0 respectively

void setup() {
      Serial.begin(115200);

  // These lines are specifically to support the Adafruit Trinket 5V 16 MHz.
  // Any other board, you can remove this part (but no harm leaving it):
#if defined(__AVR_ATtiny85__) && (F_CPU == 16000000)
  clock_prescale_set(clock_div_1);
#endif
  // END of Trinket-specific code.

    pinMode(3,OUTPUT);
    pinMode(4,OUTPUT);
    pinMode(5,OUTPUT);
    pinMode(6,OUTPUT);
    pinMode(7,OUTPUT);
    pinMode(8,OUTPUT);

    digitalWrite(3,LOW);
    digitalWrite(4,LOW);
    digitalWrite(5,LOW);
    digitalWrite(6,LOW);
    digitalWrite(7,LOW);
    digitalWrite(8,LOW);

  pixels.begin(); // INITIALIZE NeoPixel strip object (REQUIRED)

}

void loop() {
  pixels.clear(); // Set all pixel colors to 'off'
  analog = analogRead(A0);
  // The first NeoPixel in a strand is #0, second is 1, all the way up
  // to the count of pixels minus one.
  
  if(analog > 1024 - delta){
    delay(1);
    analog = analogRead(A0);
    if(analog > 1023 - delta){
       mode = 1;      
    }
  }
  if(analog > 781 - delta && analog < 781 + delta){
    delay(5);
    analog = analogRead(A0);
    if(analog > 781 - delta && analog < 781 + delta){
         mode = 2; 
    }
  }
  if(analog > 593 - delta && analog < 593 + delta){
     delay(5);
     analog = analogRead(A0);

    if(analog > 593 - delta && analog < 593 + delta){
      mode = 3;    
    }
  }

  if(analog > 436 - delta && analog < 436 + delta){
     delay(1);
     analog = analogRead(A0);

    if(analog > 436 - delta && analog < 436 + delta){
      mode = 4;    
    }
  }

  if(analog > 296 - delta && analog < 296 + delta){
     delay(1);
     analog = analogRead(A0);

    if(analog > 296 - delta && analog < 296 + delta){
      mode = 5;    
    }
  }

  if(analog > 154 - delta && analog < 154 + delta){
     delay(1);
     analog = analogRead(A0);

    if(analog > 154 - delta && analog < 154 + delta){
      mode = 6;    
    }
  }

  if(mode == 1){
    pixels.setPixelColor(0, pixels.Color(0, 0, 0));    
    pixels.setPixelColor(1, pixels.Color(0, 0, 0));    
    pixels.setPixelColor(2, pixels.Color(0, 0, 0));    
    pixels.setPixelColor(3, pixels.Color(0, 0, 0));    
    pixels.setPixelColor(4, pixels.Color(0, 0, 0));    
    pixels.setPixelColor(5, pixels.Color(255, 0, 0));    

    digitalWrite(3,LOW);
    digitalWrite(4,LOW);
    digitalWrite(5,LOW);
    digitalWrite(6,LOW);
    digitalWrite(7,LOW);
    digitalWrite(8,LOW);
    digitalWrite(3,HIGH);
    
  }
  if(mode == 2){
    pixels.setPixelColor(0, pixels.Color(0, 0, 0));    
    pixels.setPixelColor(1, pixels.Color(0, 0, 0));    
    pixels.setPixelColor(2, pixels.Color(0, 0, 0));    
    pixels.setPixelColor(3, pixels.Color(0, 0, 0));    
    pixels.setPixelColor(4, pixels.Color(255, 165, 0));    
    pixels.setPixelColor(5, pixels.Color(0, 0, 0));    
    digitalWrite(3,LOW);
    digitalWrite(4,LOW);
    digitalWrite(5,LOW);
    digitalWrite(6,LOW);
    digitalWrite(7,LOW);
    digitalWrite(8,LOW);
    digitalWrite(4,HIGH);
 
  }
  if(mode == 3){
    pixels.setPixelColor(0, pixels.Color(0, 0, 0));    
    pixels.setPixelColor(1, pixels.Color(0, 0, 0));    
    pixels.setPixelColor(2, pixels.Color(0, 0, 0));    
    pixels.setPixelColor(3, pixels.Color(255, 215, 0));    
    pixels.setPixelColor(4, pixels.Color(0, 0, 0));    
    pixels.setPixelColor(5, pixels.Color(0, 0, 0));    
    digitalWrite(3,LOW);
    digitalWrite(4,LOW);
    digitalWrite(5,LOW);
    digitalWrite(6,LOW);
    digitalWrite(7,LOW);
    digitalWrite(8,LOW);
    digitalWrite(5,HIGH);   
  }
  if(mode == 4){
    pixels.setPixelColor(0, pixels.Color(0, 0, 0));    
    pixels.setPixelColor(1, pixels.Color(0, 0, 0));    
    pixels.setPixelColor(2, pixels.Color(0, 255, 0));    
    pixels.setPixelColor(3, pixels.Color(0, 0, 0));    
    pixels.setPixelColor(4, pixels.Color(0, 0, 0));    
    pixels.setPixelColor(5, pixels.Color(0, 0, 0));    
    digitalWrite(3,LOW);
    digitalWrite(4,LOW);
    digitalWrite(5,LOW);
    digitalWrite(6,LOW);
    digitalWrite(7,LOW);
    digitalWrite(8,LOW);
    digitalWrite(6,HIGH);   
  }
  if(mode == 5){
    pixels.setPixelColor(0, pixels.Color(0, 0, 0));    
    pixels.setPixelColor(1, pixels.Color(0, 0, 255));    
    pixels.setPixelColor(2, pixels.Color(0, 0, 0));    
    pixels.setPixelColor(3, pixels.Color(0, 0, 0));    
    pixels.setPixelColor(4, pixels.Color(0, 0, 0));    
    pixels.setPixelColor(5, pixels.Color(0, 0, 0));    
    digitalWrite(3,LOW);
    digitalWrite(4,LOW);
    digitalWrite(5,LOW);
    digitalWrite(6,LOW);
    digitalWrite(7,LOW);
    digitalWrite(8,LOW);
    digitalWrite(7,HIGH);   
  }
  if(mode == 6){
    pixels.setPixelColor(0, pixels.Color(200, 0, 200));    
    pixels.setPixelColor(1, pixels.Color(0, 0, 0));    
    pixels.setPixelColor(2, pixels.Color(0, 0, 0));    
    pixels.setPixelColor(3, pixels.Color(0, 0, 0));    
    pixels.setPixelColor(4, pixels.Color(0, 0, 0));    
    pixels.setPixelColor(5, pixels.Color(0, 0, 0));    
    digitalWrite(3,LOW);
    digitalWrite(4,LOW);
    digitalWrite(5,LOW);
    digitalWrite(6,LOW);
    digitalWrite(7,LOW);
    digitalWrite(8,LOW);
    digitalWrite(8,HIGH);   
  }
  
  pixels.show();   // Send the updated pixel colors to the hardware.
  delay(1); // Pause before next pass through loop

    Serial.println(analog);

}

```

# Synth code with potentiometer

```

/*  Example playing a sinewave at a set frequency,
    using Mozzi sonification library.

DIRT SYNTH IS JUST SINE WAVE WITH FREQUENCY BASED ON AN ANALOG VOLTAGE ON THE CIRCUIT BOARD

    Demonstrates the use of Oscil to play a wavetable.

    Circuit: Audio output on digital pin 9 on a Uno or similar, or
    DAC/A14 on Teensy 3.1, or
    check the README or http://sensorium.github.io/Mozzi/

    Mozzi documentation/API
    https://sensorium.github.io/Mozzi/doc/html/index.html

    Mozzi help/discussion/announcements:
    https://groups.google.com/forum/#!forum/mozzi-users

    Tim Barrass 2012, CC by-nc-sa.
*/

int voltage = 0;
#include <Adafruit_NeoPixel.h>

#include <MozziGuts.h>
#include <Oscil.h> // oscillator template
#include <tables/sin2048_int8.h> // sine table for oscillator

// use: Oscil <table_size, update_rate> oscilName (wavetable), look in .h file of table #included above
Oscil <SIN2048_NUM_CELLS, AUDIO_RATE> aSin(SIN2048_DATA);

// use #define for CONTROL_RATE, not a constant
#define CONTROL_RATE 64 // Hz, powers of 2 are most reliable

void setup(){
  startMozzi(CONTROL_RATE); // :)
  aSin.setFreq(2600); // set the frequency 2600 HZ! HACK THE PLANET!
    pinMode(9,OUTPUT); 

}

void updateControl(){
  // put changing controls in here
}

AudioOutput_t updateAudio(){
  return MonoOutput::from8Bit(aSin.next()); // return an int signal centred around 0
}

void loop(){
  
  voltage = analogRead(A0);
  aSin.setFreq(440 + 3*voltage);  
  audioHook(); // required here
  
}
```

# CODE FOR 9 LINE CONTROLLER: 9 PIXELS, 9 BUTTONS

```

#include <Adafruit_NeoPixel.h>
#ifdef __AVR__
#endif

// Which pin on the Arduino is connected to the NeoPixels?
#define PIN        12 // On Trinket or Gemma, suggest changing this to 1

// How many NeoPixels are attached to the Arduino?
#define NUMPIXELS 9 // 
//there are 9

// When setting up the NeoPixel library, we tell it how many pixels,  
// and which pin to use to send signals. Note that for older NeoPixel
// strips you might need to change the third parameter -- see the
// strandtest example for more information on possible values.
Adafruit_NeoPixel pixels(NUMPIXELS, PIN, NEO_GRB + NEO_KHZ800);

int analog = 0;
int delta = 20;
int mode = 1;//modes are 1,2,3,4,5,6,7,8,9 which are pixel 8,7,6,5,4,3,2,1, and 0 respectively

void setup() {
      Serial.begin(115200);

  // These lines are specifically to support the Adafruit Trinket 5V 16 MHz.
  // Any other board, you can remove this part (but no harm leaving it):
#if defined(__AVR_ATtiny85__) && (F_CPU == 16000000)
  clock_prescale_set(clock_div_1);
#endif
  // END of Trinket-specific code.

    pinMode(3,OUTPUT);
    pinMode(4,OUTPUT);
    pinMode(5,OUTPUT);
    pinMode(6,OUTPUT);
    pinMode(7,OUTPUT);
    pinMode(8,OUTPUT);

    digitalWrite(3,LOW);
    digitalWrite(4,LOW);
    digitalWrite(5,LOW);
    digitalWrite(6,LOW);
    digitalWrite(7,LOW);
    digitalWrite(8,LOW);

  pixels.begin(); // INITIALIZE NeoPixel strip object (REQUIRED)

}

void loop() {
  pixels.clear(); // Set all pixel colors to 'off'
  analog = analogRead(A0);
  // The first NeoPixel in a strand is #0, second is 1, all the way up
  // to the count of pixels minus one.
  
  if(analog > 1024 - delta){
    delay(1);
    analog = analogRead(A0);
    if(analog > 1023 - delta){
       mode = 1;      
    }
  }
  if(analog > 836 - delta && analog < 836 + delta){
    delay(5);
    analog = analogRead(A0);
    if(analog > 836 - delta && analog < 836 + delta){
         mode = 2; 
    }
  }
  if(analog > 690 - delta && analog < 690 + delta){
     delay(5);
     analog = analogRead(A0);

    if(analog > 690 - delta && analog < 690 + delta){
      mode = 3;    
    }
  }

  if(analog > 569 - delta && analog < 569 + delta){
     delay(1);
     analog = analogRead(A0);

    if(analog > 569 - delta && analog < 569 + delta){
      mode = 4;    
    }
  }

  if(analog > 464 - delta && analog < 464 + delta){
     delay(1);
     analog = analogRead(A0);

    if(analog > 464 - delta && analog < 464 + delta){
      mode = 5;    
    }
  }

  if(analog > 372 - delta && analog < 372 + delta){
     delay(1);
     analog = analogRead(A0);

    if(analog > 372 - delta && analog < 372 + delta){
      mode = 6;    
    }
  }

  if(analog > 283 - delta && analog < 283 + delta){
     delay(1);
     analog = analogRead(A0);

    if(analog > 283 - delta && analog < 283 + delta){
      mode = 7;    
    }
  }

  if(analog > 195 - delta && analog < 195 + delta){
     delay(1);
     analog = analogRead(A0);

    if(analog > 195 - delta && analog < 195 + delta){
      mode = 8;    
    }
  }

  if(analog > 103 - delta && analog < 103 + delta){
     delay(1);
     analog = analogRead(A0);

    if(analog > 103 - delta && analog < 103 + delta){
      mode = 9;    
    }
  }

  if(mode == 1){
    pixels.setPixelColor(0, pixels.Color(0, 0, 0));    
    pixels.setPixelColor(1, pixels.Color(0, 0, 0));    
    pixels.setPixelColor(2, pixels.Color(0, 0, 0));    
    pixels.setPixelColor(3, pixels.Color(0, 0, 0));    
    pixels.setPixelColor(4, pixels.Color(0, 0, 0));    
    pixels.setPixelColor(5, pixels.Color(0, 0, 0));    
    pixels.setPixelColor(6, pixels.Color(0, 0, 0));    
    pixels.setPixelColor(7, pixels.Color(0, 0, 0));    
    pixels.setPixelColor(8, pixels.Color(255, 0, 0));    

  }
  if(mode == 2){
    pixels.setPixelColor(0, pixels.Color(0, 0, 0));    
    pixels.setPixelColor(1, pixels.Color(0, 0, 0));    
    pixels.setPixelColor(2, pixels.Color(0, 0, 0));    
    pixels.setPixelColor(3, pixels.Color(0, 0, 0));    
    pixels.setPixelColor(4, pixels.Color(0, 0, 0));    
    pixels.setPixelColor(5, pixels.Color(0, 0, 0));    
    pixels.setPixelColor(6, pixels.Color(0, 0, 0));    
    pixels.setPixelColor(7, pixels.Color(255, 0, 0));    
    pixels.setPixelColor(8, pixels.Color(0, 0, 0));    

  }
  if(mode == 3){
    pixels.setPixelColor(0, pixels.Color(0, 0, 0));    
    pixels.setPixelColor(1, pixels.Color(0, 0, 0));    
    pixels.setPixelColor(2, pixels.Color(0, 0, 0));    
    pixels.setPixelColor(3, pixels.Color(0, 0, 0));    
    pixels.setPixelColor(4, pixels.Color(0, 0, 0));    
    pixels.setPixelColor(5, pixels.Color(0, 0, 0));    
    pixels.setPixelColor(6, pixels.Color(255, 0, 0));    
    pixels.setPixelColor(7, pixels.Color(0, 0, 0));    
    pixels.setPixelColor(8, pixels.Color(0, 0, 0));    

  }
  if(mode == 4){
    pixels.setPixelColor(0, pixels.Color(0, 0, 0));    
    pixels.setPixelColor(1, pixels.Color(0, 0, 0));    
    pixels.setPixelColor(2, pixels.Color(0, 0, 0));    
    pixels.setPixelColor(3, pixels.Color(0, 0, 0));    
    pixels.setPixelColor(4, pixels.Color(0, 0, 0));    
    pixels.setPixelColor(5, pixels.Color(255, 0, 0));    
    pixels.setPixelColor(6, pixels.Color(0, 0, 0));    
    pixels.setPixelColor(7, pixels.Color(0, 0, 0));    
    pixels.setPixelColor(8, pixels.Color(0, 0, 0));    

  }
  if(mode == 5){
    pixels.setPixelColor(0, pixels.Color(0, 0, 0));    
    pixels.setPixelColor(1, pixels.Color(0, 0, 0));    
    pixels.setPixelColor(2, pixels.Color(0, 0, 0));    
    pixels.setPixelColor(3, pixels.Color(0, 0, 0));    
    pixels.setPixelColor(4, pixels.Color(255, 0, 0));    
    pixels.setPixelColor(5, pixels.Color(0, 0, 0));    
    pixels.setPixelColor(6, pixels.Color(0, 0, 0));    
    pixels.setPixelColor(7, pixels.Color(0, 0, 0));    
    pixels.setPixelColor(8, pixels.Color(0, 0, 0));    

  }
  if(mode == 6){
    pixels.setPixelColor(0, pixels.Color(0, 0, 0));    
    pixels.setPixelColor(1, pixels.Color(0, 0, 0));    
    pixels.setPixelColor(2, pixels.Color(0, 0, 0));    
    pixels.setPixelColor(3, pixels.Color(255, 0, 0));    
    pixels.setPixelColor(4, pixels.Color(0, 0, 0));    
    pixels.setPixelColor(5, pixels.Color(0, 0, 0));    
    pixels.setPixelColor(6, pixels.Color(0, 0, 0));    
    pixels.setPixelColor(7, pixels.Color(0, 0, 0));    
    pixels.setPixelColor(8, pixels.Color(0, 0, 0));    

  }

  if(mode == 7){
    pixels.setPixelColor(0, pixels.Color(0, 0, 0));    
    pixels.setPixelColor(1, pixels.Color(0, 0, 0));    
    pixels.setPixelColor(2, pixels.Color(255, 0, 0));    
    pixels.setPixelColor(3, pixels.Color(0, 0, 0));    
    pixels.setPixelColor(4, pixels.Color(0, 0, 0));    
    pixels.setPixelColor(5, pixels.Color(0, 0, 0));    
    pixels.setPixelColor(6, pixels.Color(0, 0, 0));    
    pixels.setPixelColor(7, pixels.Color(0, 0, 0));    
    pixels.setPixelColor(8, pixels.Color(0, 0, 0));    

 }
  if(mode == 8){
    pixels.setPixelColor(0, pixels.Color(0, 0, 0));    
    pixels.setPixelColor(1, pixels.Color(255, 0, 0));    
    pixels.setPixelColor(2, pixels.Color(0, 0, 0));    
    pixels.setPixelColor(3, pixels.Color(0, 0, 0));    
    pixels.setPixelColor(4, pixels.Color(0, 0, 0));    
    pixels.setPixelColor(5, pixels.Color(0, 0, 0));    
    pixels.setPixelColor(6, pixels.Color(0, 0, 0));    
    pixels.setPixelColor(7, pixels.Color(0, 0, 0));    
    pixels.setPixelColor(8, pixels.Color(0, 0, 0));    

  }
  if(mode == 9){
    pixels.setPixelColor(0, pixels.Color(255, 0, 0));    
    pixels.setPixelColor(1, pixels.Color(0, 0, 0));    
    pixels.setPixelColor(2, pixels.Color(0, 0, 0));    
    pixels.setPixelColor(3, pixels.Color(0, 0, 0));    
    pixels.setPixelColor(4, pixels.Color(0, 0, 0));    
    pixels.setPixelColor(5, pixels.Color(0, 0, 0));    
    pixels.setPixelColor(6, pixels.Color(0, 0, 0));    
    pixels.setPixelColor(7, pixels.Color(0, 0, 0));    
    pixels.setPixelColor(8, pixels.Color(0, 0, 0));    

  }

  pixels.show();   // Send the updated pixel colors to the hardware.
  delay(1); // Pause before next pass through loop

    Serial.println(analog);

}
```

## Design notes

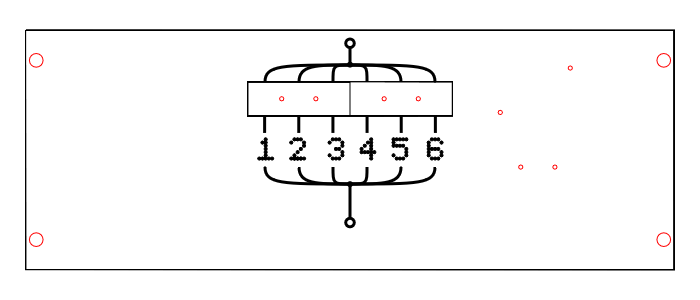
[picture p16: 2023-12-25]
mechanicals/rack-mems-6portcal.png

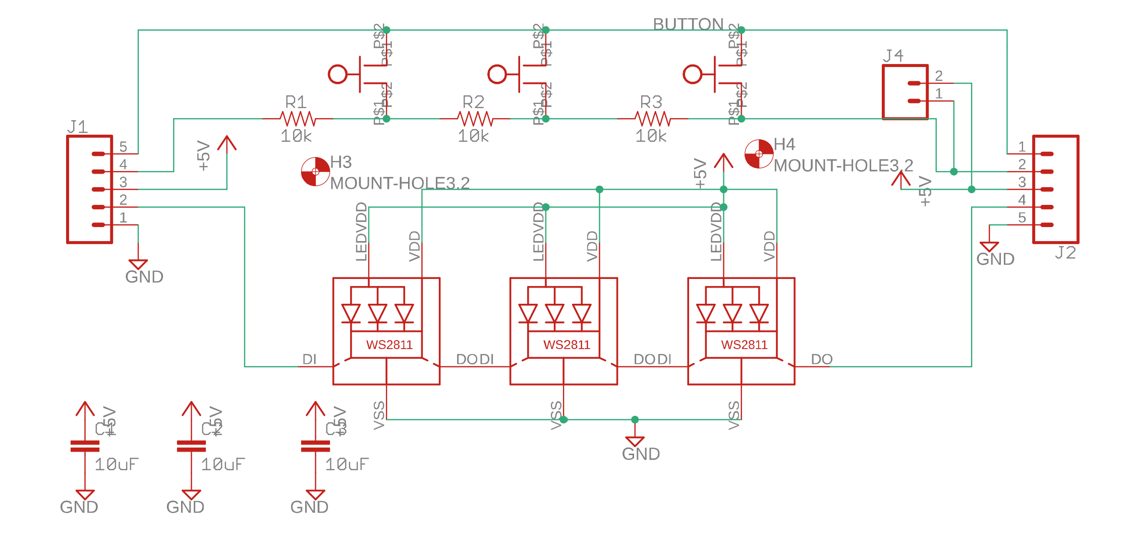
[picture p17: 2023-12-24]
switchotron-3buttons-3lights/eagle-screenshot-schematic.png

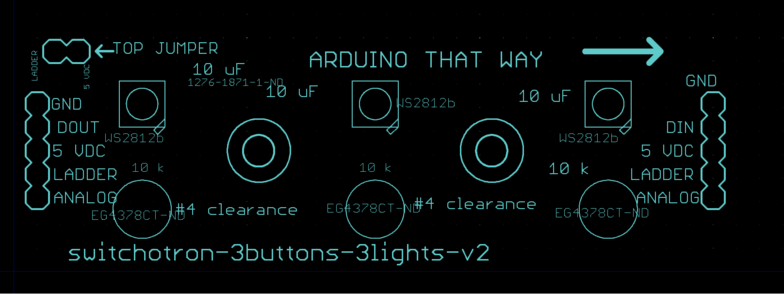
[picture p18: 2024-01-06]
switchotron-3buttons-3lights/gerber-silkscreen-screenshot-v2.png

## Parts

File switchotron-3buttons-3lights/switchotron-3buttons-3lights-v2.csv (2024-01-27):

Part | Value | Device | Package | Description
C1 | 10uF
C2 | 10uF
C3 | 10uF
Part;"Value";"Device";"Package";"Description";"POPULARITY";"PROD_ID";"VALUE";
C1;"10uF";"10UF-0603-6.3V-20%";"0603";"10.0µF ceramic capacitors";"";"CAP-11015";"10uF";
C2;"10uF";"10UF-0603-6.3V-20%";"0603";"10.0µF ceramic capacitors";"";"CAP-11015";"10uF";
C3;"10uF";"10UF-0603-6.3V-20%";"0603";"10.0µF ceramic capacitors";"";"CAP-11015";"10uF";
LED1;"WS2812B5050-NARROW";"WS2812B5050-NARROW";"WS2812B-NARROW";"";"";"";"";
LED2;"WS2812B5050-NARROW";"WS2812B5050-NARROW";"WS2812B-NARROW";"";"";"";"";
LED3;"WS2812B5050-NARROW";"WS2812B5050-NARROW";"WS2812B-NARROW";"";"";"";"";
R1;"10k";"10KOHM-0603-1/10W-1%";"0603";"10kΩ resistor";"";"RES-00824";"10k";
R2;"10k";"10KOHM-0603-1/10W-1%";"0603";"10kΩ resistor";"";"RES-00824";"10k";
R3;"10k";"10KOHM-0603-1/10W-1%";"0603";"10kΩ resistor";"";"RES-00824";"10k";

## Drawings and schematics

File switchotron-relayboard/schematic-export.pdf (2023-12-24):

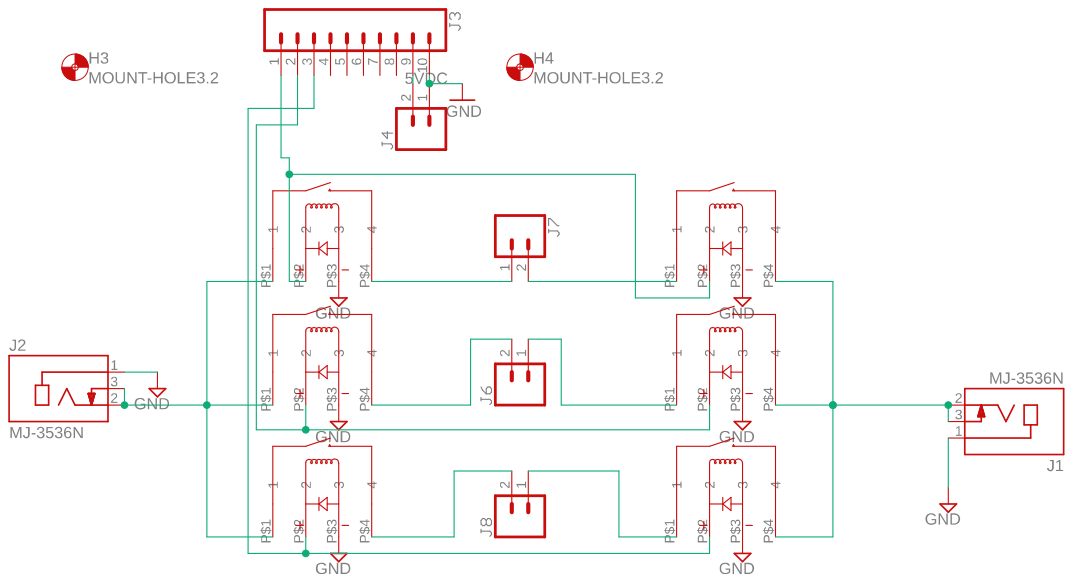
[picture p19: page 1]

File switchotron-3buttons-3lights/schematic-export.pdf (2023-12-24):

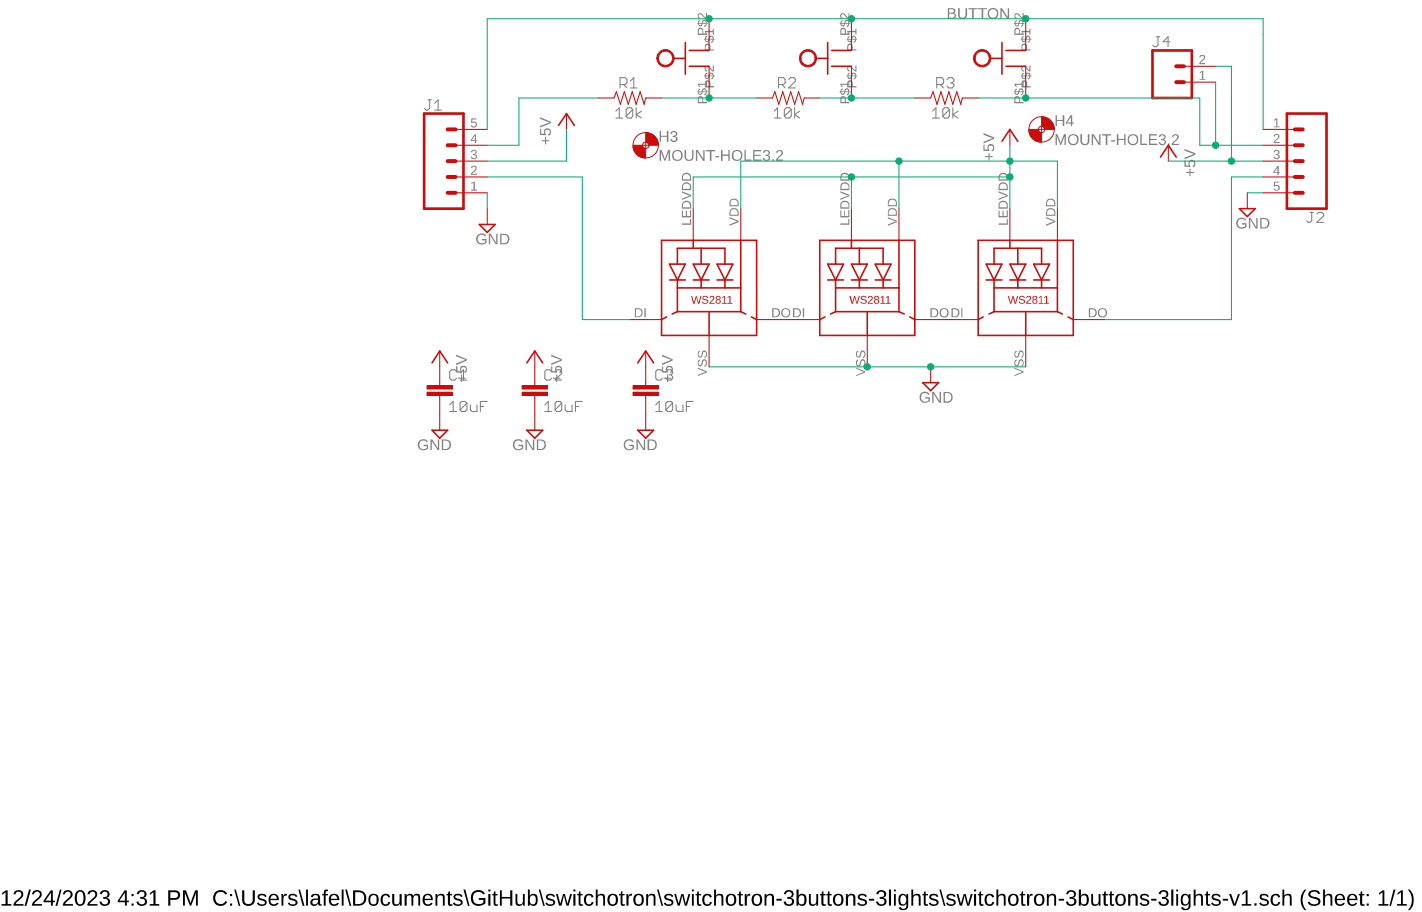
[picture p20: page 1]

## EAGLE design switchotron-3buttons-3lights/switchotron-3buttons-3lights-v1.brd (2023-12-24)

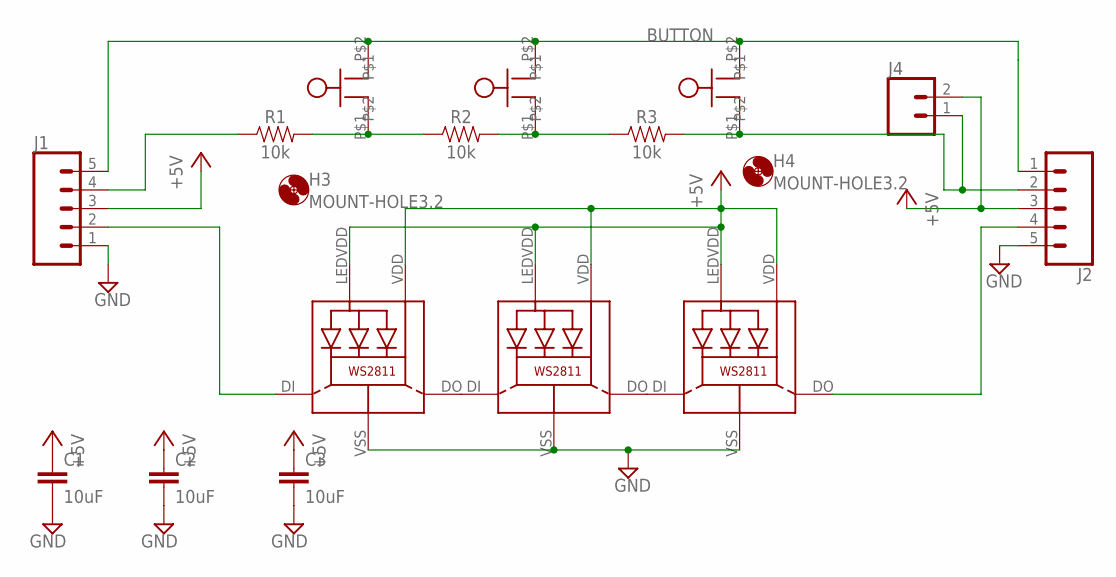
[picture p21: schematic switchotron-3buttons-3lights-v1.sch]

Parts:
C1, C2, C3: 10uF; 0603
H3, H4: MOUNT-HOLE3.2; 3,2
J1, J2: CONN_05; 1X05
J4: CONN_02; 1X02
LED1, LED2, LED8: WS28115050
R1, R2, R3: 10k; 0603
U$1, U$4, U$5: BUTTON

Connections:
+5V: C1.1, C2.1, C3.1, J1.3, J2.3, J4.2, LED1.LEDVDD, LED1.VDD, LED2.LEDVDD, LED2.VDD, LED8.LEDVDD, LED8.VDD
BUTTON: J1.5, J2.1, U$1.P$2, U$4.P$2, U$5.P$2
GND: C1.2, C2.2, C3.2, J1.1, J2.5, LED1.VSS (GND), LED2.VSS (GND), LED8.VSS (GND)
unnamed: LED1.DO, LED2.DI
unnamed: R1.2, R2.1, U$1.P$1
unnamed: R2.2, R3.1, U$4.P$1
unnamed: J2.2, J4.1, R3.2, U$5.P$1
unnamed: J1.4, R1.1
unnamed: LED2.DO, LED8.DI
unnamed: J1.2, LED1.DI
unnamed: J2.4, LED8.DO

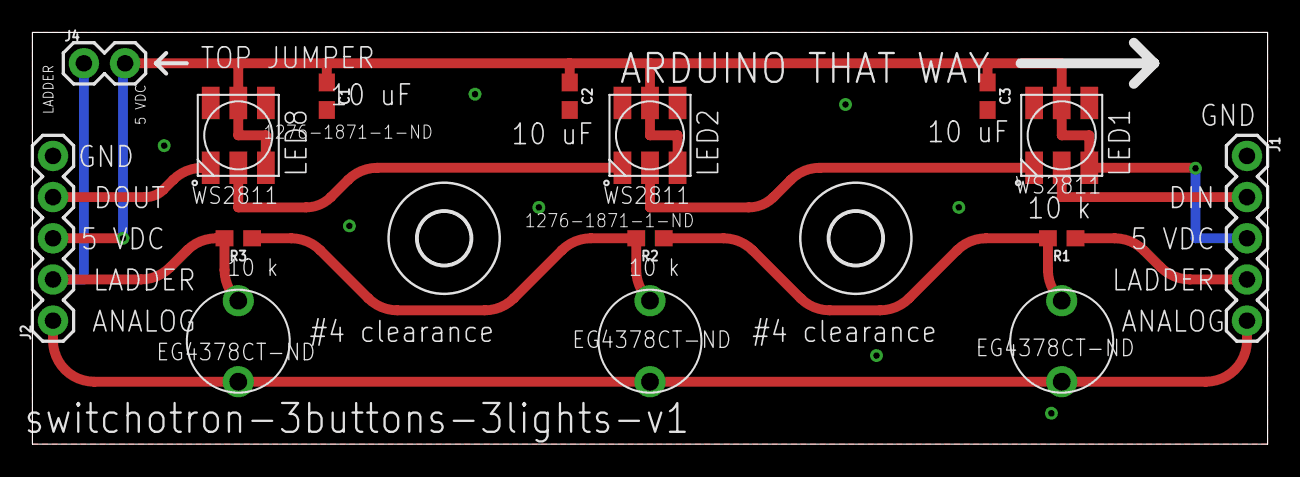
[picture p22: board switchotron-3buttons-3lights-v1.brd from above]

Board: 2 copper layers, 76.2 x 25.4 mm, 17 parts (0 on the bottom side), 11 nets.

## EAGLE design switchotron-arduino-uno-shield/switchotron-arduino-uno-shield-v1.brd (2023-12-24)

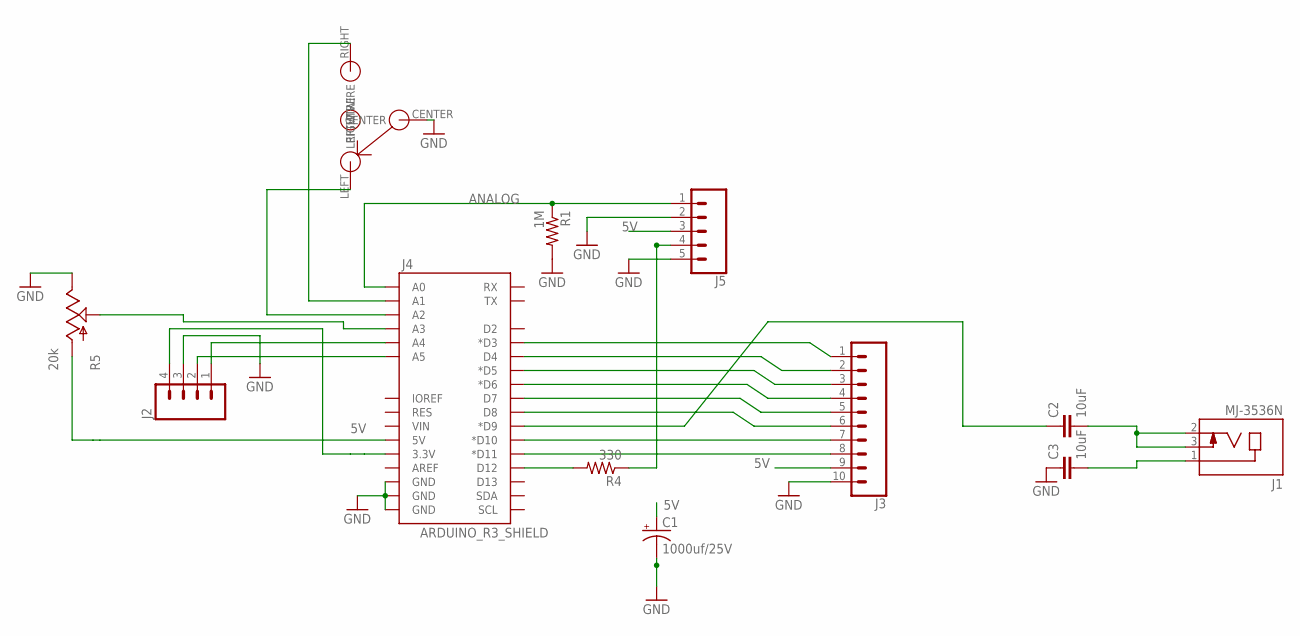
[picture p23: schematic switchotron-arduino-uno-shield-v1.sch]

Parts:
C1: 1000uf/25V; CPOL-RADIAL-1000UF-25V-KIT
C2, C3: 10uF; 0805
J1: MJ-3536N; CUI_MJ-3536N
J2: M04PTH; 1X04
J3: CONN_10"; 1X10
J4: ARDUINO_R3_SHIELD; UNO_R3_SHIELD
J5: CONN_05; 1X05
R1: 1M; R0603
R4: 330; R0603
R5: 20k; ALPS_POT_KIT
SW3: ON-OFF-ON-360-1013-ND; 360-1013-ND

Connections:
5V: C1.+, J3.9, J4.5V, J5.3, R5.P$3 (A)
ANALOG: J4.A0, J5.1, R1.1
BUTTON: J4.A1, SW3.RIGHT (RIGHTWIRE)
CL: J2.2, J4.A5
DA: J2.1, J4.A4
GND: C1.-, C3.1, J2.3, J3.10, J4.GND@0 (GND), J4.GND@1 (GND), J4.GND@2 (GND), J5.2, J5.5, R1.2, R5.P$1 (E), SW3.CENTER
unnamed: J4.D12, R4.2
unnamed: J4.A3, R5.P$2 (S)
unnamed: J3.8, J4.D11 (*D11)
unnamed: J3.7, J4.D10 (*D10)
unnamed: J3.6, J4.D8
unnamed: J3.5, J4.D7
unnamed: J3.4, J4.D6 (*D6)
unnamed: J3.3, J4.D5 (*D5)
unnamed: J3.2, J4.D4
unnamed: J4.A2, SW3.LEFT (LEFTWIRE)
unnamed: J3.1, J4.D3 (*D3)
unnamed: C3.2, J1.1
unnamed: C2.2, J1.2, J1.3
unnamed: C2.1, J4.D9 (*D9)
unnamed: J5.4, R4.1
VCC: J2.4, J4.3.3V

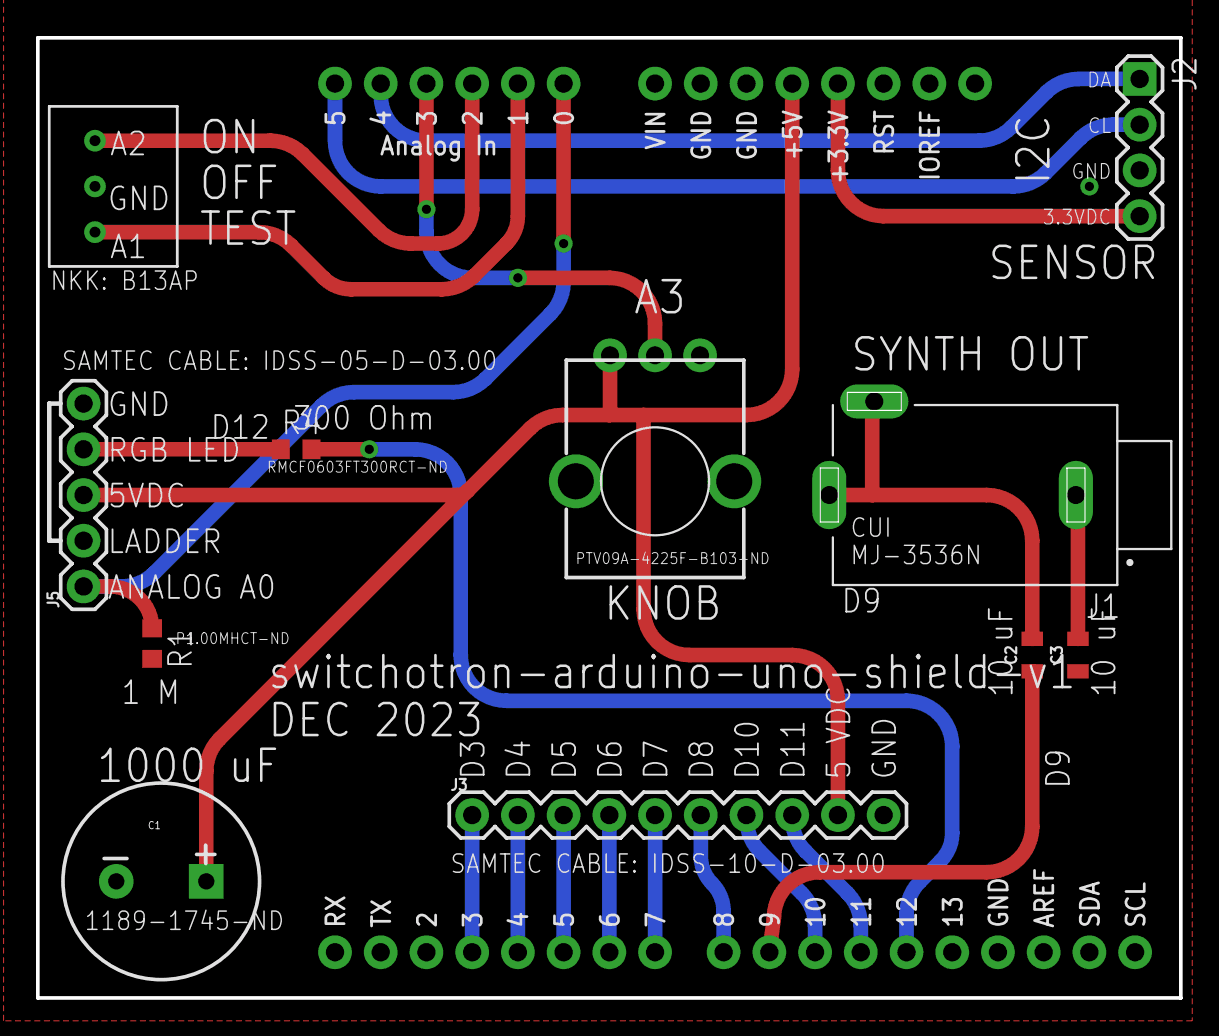
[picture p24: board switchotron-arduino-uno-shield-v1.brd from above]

Board: 2 copper layers, 63.5 x 53.3 mm, 12 parts (0 on the bottom side), 22 nets.

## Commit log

2023-12-24 switchotron is a system for controlling switches
    [copper_bottom.gbr, copper_top.gbr, gerber_job.gbrjob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]
2023-12-24 uno mounting hole documentation
2023-12-24 added circular hole version of panel cutout
2023-12-24 adding schematics
2023-12-24 more schematics
2023-12-24 still more schematics
2023-12-25 more mechanicals design, now for mems switches controlled from rack mount
2023-12-25 mems driver draft board
    [switchotron-mems-driver-v1.brd, switchotron-mems-driver-v1.sch]
2023-12-25 mems driver design work
    [switchotron-mems-driver-v1.brd, switchotron-mems-driver-v1.sch]
2024-01-06 new version of 3 button 3 light board with WS2812B instead of WS2811
    [copper_top.gbr, gerber_job.gbrjob, profile.gbr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]
2024-01-06 images for the documentation to document the versioning of the board with the LEDs
2024-01-07 moved the LEDs up to 0.75 inches y axis position
    [switchotron-3buttons-3lights-v2.GTL, switchotron-3buttons-3lights-v2.GTO, switchotron-3buttons-3lights-v2.GTP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]
2024-01-15 UPDATE README AND ALSO WORKING ON BILL OF MATERIALS FOR PCBA
    [3buttons-3lights-kicad.kicad_pcb, 3buttons-3lights-kicad.kicad_sch, learning-kicad-tutorial.kicad_pcb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]
2024-01-27 UPDATE CODE
    [switchotron-3buttons-3lights-v2.csv]
2024-02-15 the code now has serial control as well as buttons, no mode switch needed
2024-04-03 arduino code, copies of tested recently code

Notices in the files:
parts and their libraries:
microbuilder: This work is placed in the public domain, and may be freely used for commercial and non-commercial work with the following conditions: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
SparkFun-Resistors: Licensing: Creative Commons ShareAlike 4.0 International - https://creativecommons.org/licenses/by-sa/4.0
